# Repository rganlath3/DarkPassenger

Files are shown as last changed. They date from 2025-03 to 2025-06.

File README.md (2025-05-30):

# Dark Passenger



[]()

A modular payload for use as a ROS learning platform. Each floor of the chassis delivers different capabilities. The initial design is mounted on a differential drive roomba with plans to expand to treaded or quad-coptor platforms.

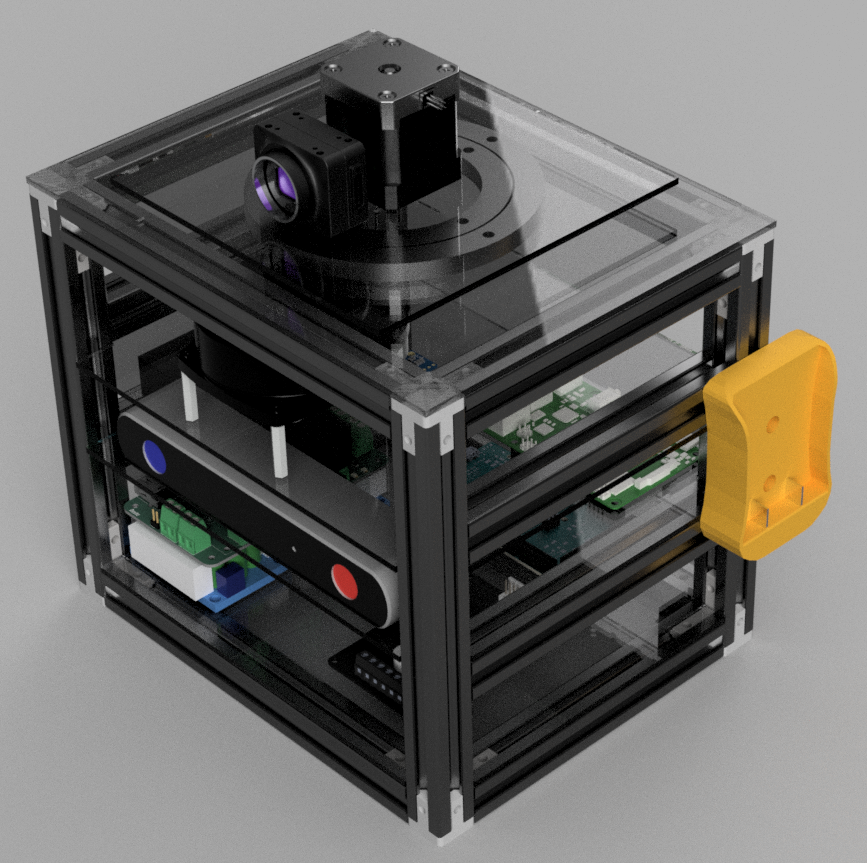
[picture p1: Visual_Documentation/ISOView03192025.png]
Dark Passenger Iso View


<!-- ABOUT THE PROJECT -->
## About The Project
The idea was to reuse a cheap roomba to create a platform for learning ROS2 and sensor integration. The end goal is to have a project incorporate aluminum extrusion chassis, working with acrylic, ESP32-S3, KiCAD PCB Development, stepper motors, thermal camera, depth camera, LIDAR, slip rings, DC motor controllers, encoders, 3D printing, INS sensor fusion, relays, GPS, SLAM, NAV2 (navigation stack) and power distribution.

### Design Tools & Requirements

#### Software Requirements
- VS Code (Programming IDE)
- Autodesk Fusion360 (Free CAD Software)
- KiCAD 9.0 (Open Source PCB Design Software)
- Ultimaker Cura (Free 3D Slicing Software)

#### Hardware Requirements
- Raspberry Pi 5
- 32GB+ SD Card
- 1x Dewalt 20VDC 2Ah Battery

## Hardware Development

### Bill of Materials
Coming Soon

### Hardware Used
#### Chassis
* 2020 T Slot Aluminum Extrusion
* 2020 2-Way Corner Brackets
* 2020 3-Way Corner Brackets
* M5 T Nuts and Screws
* 8x10 Black Translucent Acrylic Sheets 1/8" thick.

#### Floor 1
* 2x DROK Step Down Voltage Regulator
* 2x 3V Relay Modules
* 1x Custom Power Distribution PCB
* 1x Custom ESP3 GPIO PCB
* 1x ESP32-S3-N8R2
* 1x COB LED Strip Yellow
* 1x COB LED Strip Red
* 1x Cytron Dual Channel 10A DC Motor Driver
* 1x Quick Disconnect 12Pin Connector
* 1x MPU9250 IMU
* 1x GY-NEO6MV2 GPS Module

#### Floor 2
* 2x Acer USB Powered Hub
* 1x Raspberry Pi 5 (SBC)
* 1x Respeaker Microphone Array
* 1x ZED Stereo Labs Depth Camera

#### Floor 3
* 1x A1M8 RPLIDAR LIDAR Sensor
* 1x GPS Antenna

#### Floor 4
* 1x Custom ESP3 GPIO PCB
* 1x ESP32-S3-N8R2
* 1x Taidacent Hollow Slip Ring (Maybe 2x)
* 1x 5mm Flange Coupler
* 2x TMC2209 V1.3 Stepper Motor Driver
* 2x NEMA 17 Stepper (2A, 59Ncm), 48mm
* 1x Chameleon Camera Teledyne CM3-U3-13S2C-CS
* 3x 3V Relay Modules
* 1x MDD3A Dual Channel 3A DC Motor Driver
* 1x NERF Gun Gearbox
* 1x Laser Diode, 5V 1mA
* 1x COB LED Strip Yellow
* 1x 5V or 12V Cooling Fan

#### Misc
* Various Capacitors, Resistors, SMD LEDs, JST Connectors, Wire Crimps, etc.
* Various stranded wire lengths and colors: 16AWG, 22AWG.
* 1x 2.1mm DC Barrel Jacks Pair (Power Input)
* 1x SPST 20A Heavy Duty Toggle Switch (Projector Power and Pi Power)
* 2x SPST 5A Mini Toggle Switch (LED Power)
* 3D Printer: Creality CR-10SProV2

### Internal Block Diagram
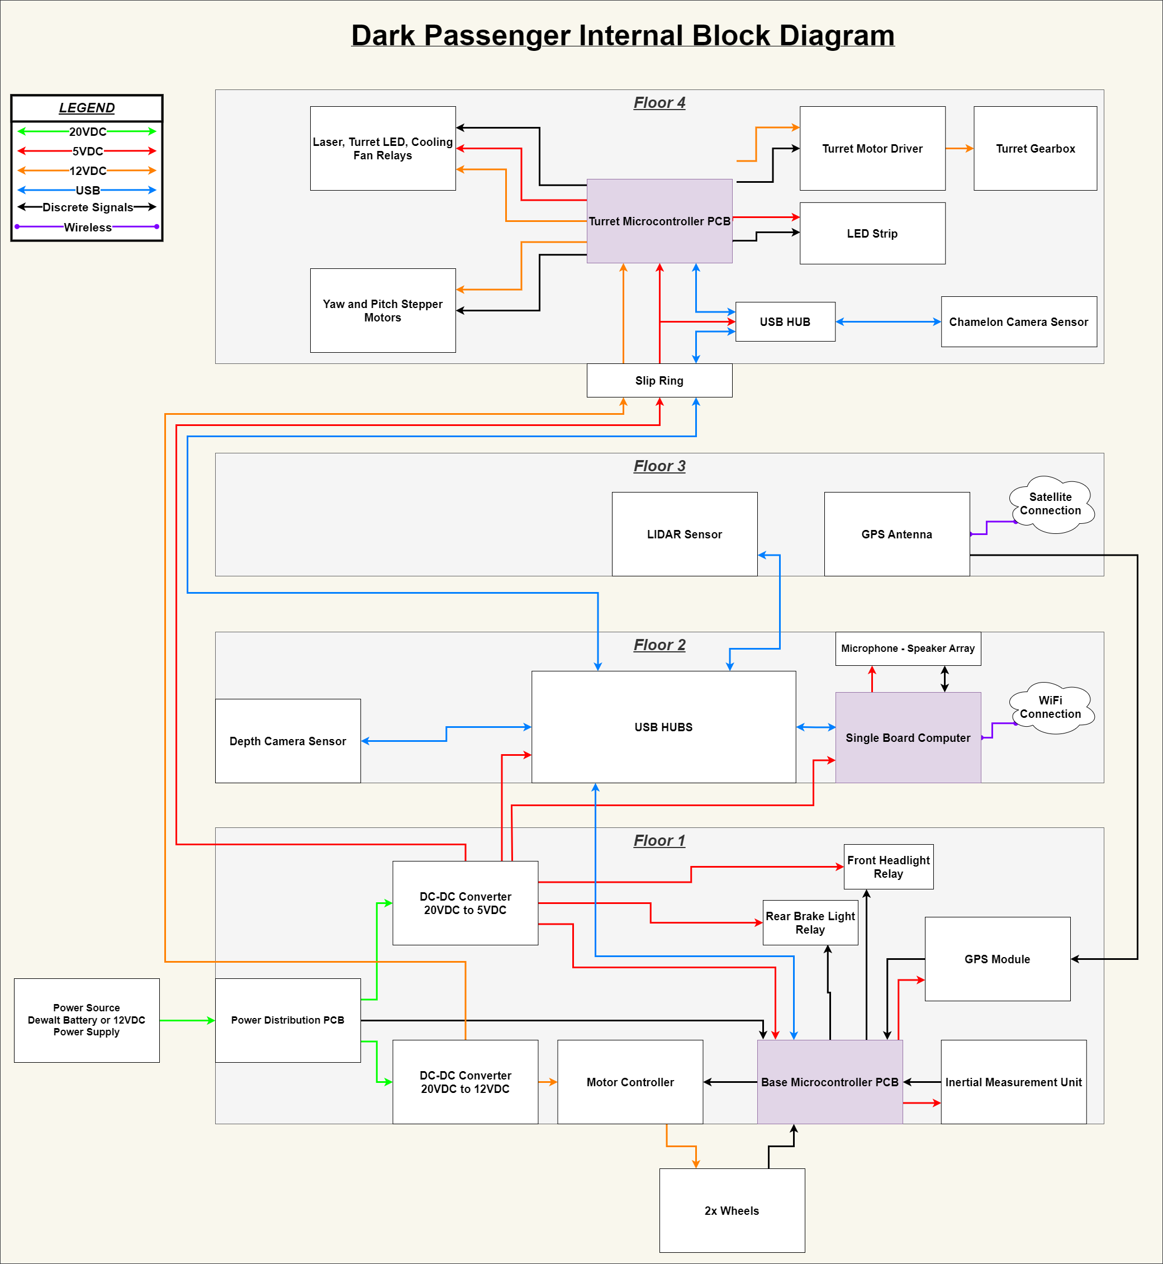
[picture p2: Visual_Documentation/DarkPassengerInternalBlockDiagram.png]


### Electrical Interconnect Diagram
[Electrical Interconnect Diagram](/Hardware_Development/DrawIO/DarkPassengerElectricalInterconnect.pdf)
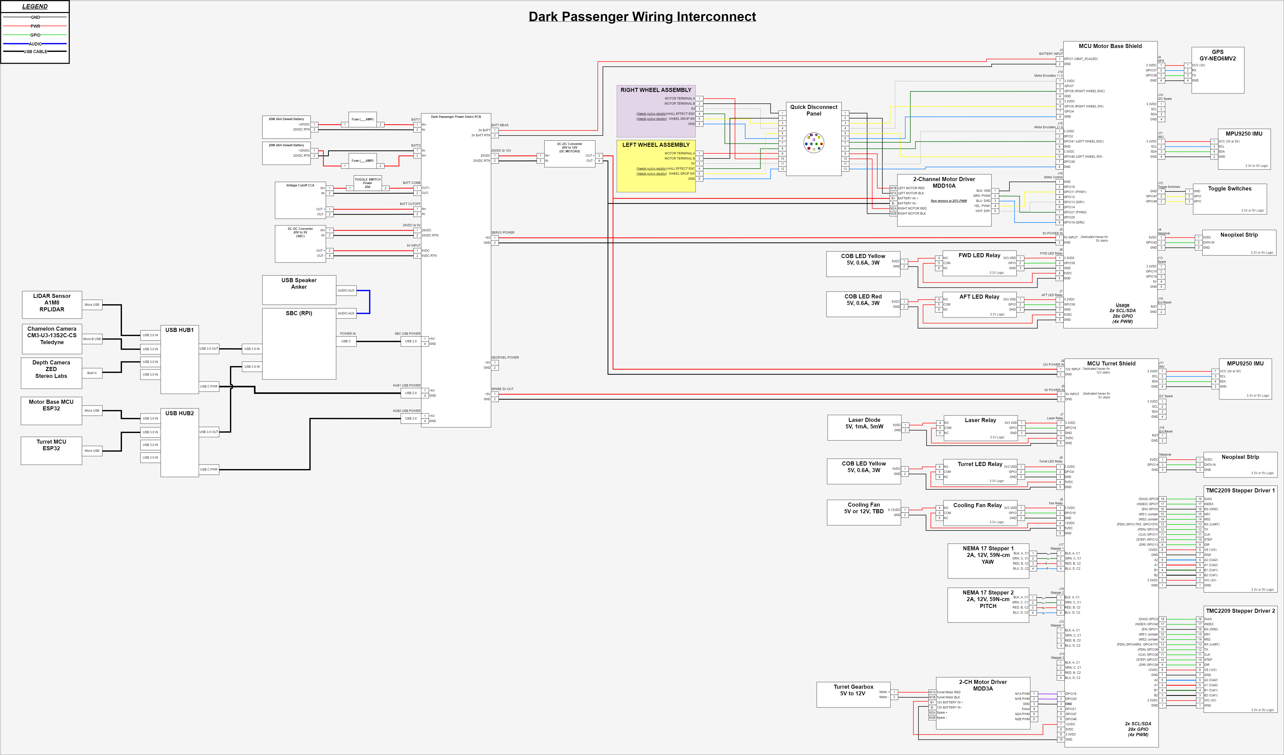
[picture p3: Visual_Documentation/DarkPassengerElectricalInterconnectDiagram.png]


### PCBs
#### Power Distribution PCB
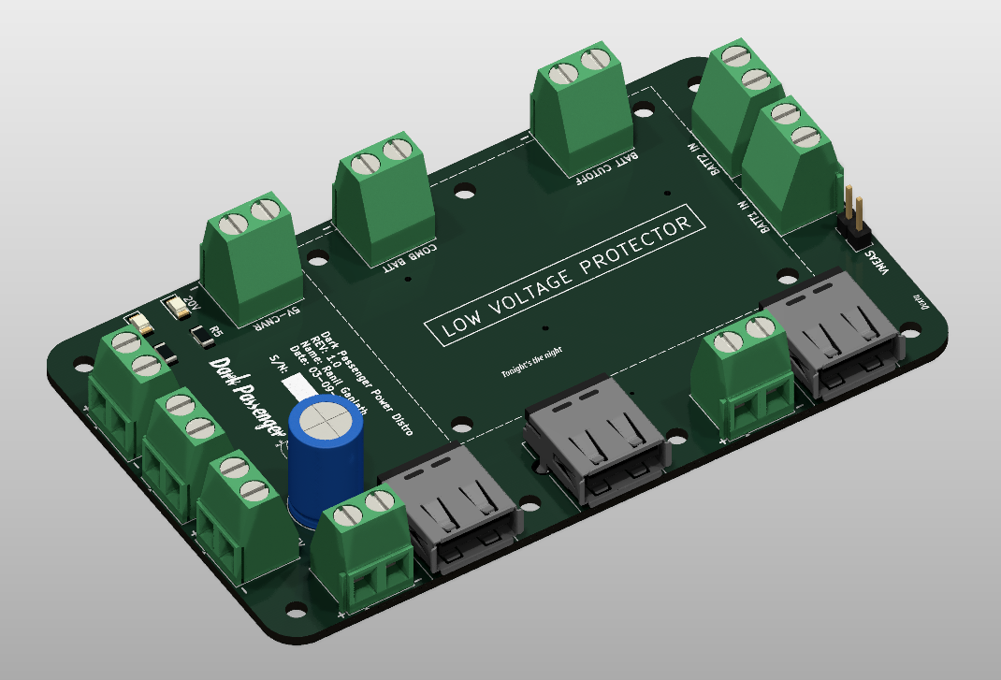
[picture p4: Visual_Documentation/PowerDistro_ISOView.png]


This PCB is used to stack 2x DC-DC converters below and a voltage cutoff board on the top. This PCB distributes power from battery inputs to get converted to 12V and 5V. It interfaces with the following components:

- Up to 2x 2Ah Dewalt Batteries
- Voltage Cutoff CCA (TBD)
- 20VDC to 5VDC Converter (TBD)
- 20VDC to 12VDC Converter (TBD)
- 3x Powered USB Ports
- Spare I2C

#### Base MCU PCB
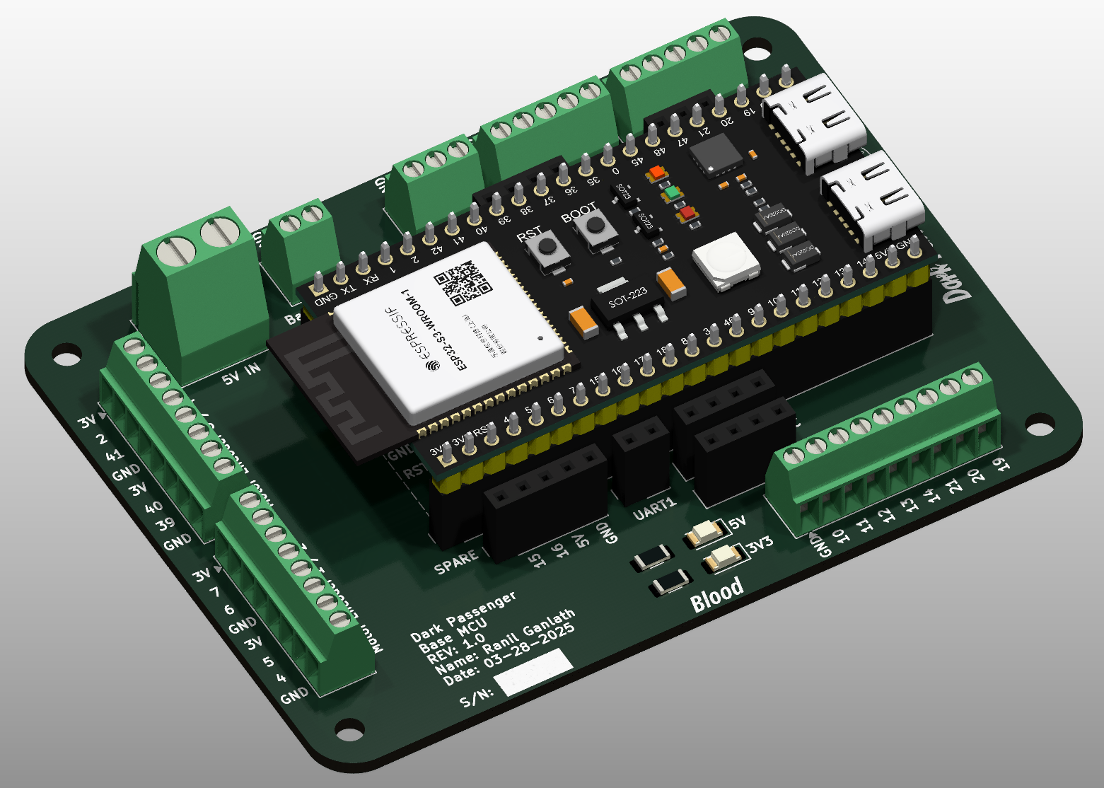
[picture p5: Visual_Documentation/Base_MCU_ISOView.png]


This PCB is used to interface an ESP32-S3 with the following components:

- GPS Module (GY-NEO6mV2)
- MPU9250 IMU
- Spare I2C
- 2x Toggle Switches
- Neopixel Strip
- 2x Spare GPIOs
- External Reset
- 2x Channel Motor Driver (MDD10A)
- Battery Scaled Input
- Motor Encoders
- FWD LED Relay
- AFT LED Relay
- 5V Distribution

#### Turret MCU PCB
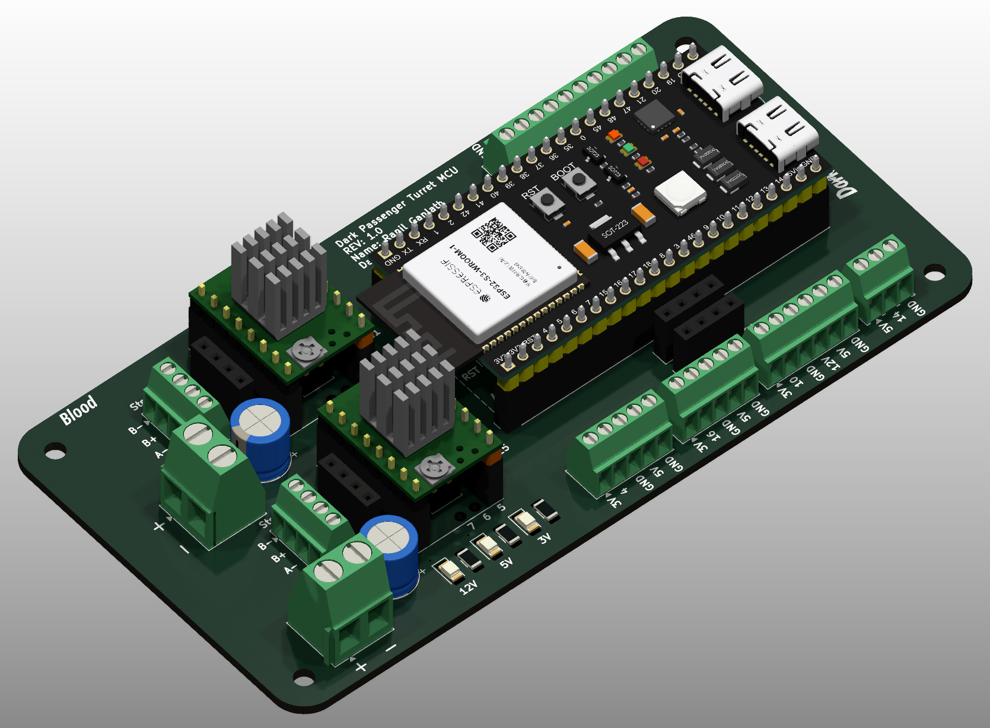
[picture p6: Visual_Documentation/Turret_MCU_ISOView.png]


This PCB is used to interface an ESP32-S3 with the following components:

- GPS Module (GY-NEO6mV2)
- MPU9250 IMU
- Spare I2C
- Neopixel Strip
- External Reset
- 2x Channel Motor Driver (MDD3A)
- 2x NEMA17 Stepper Motors
- 2x TMC2209 Stepper Driver
- Laser Relay
- Turret LED Relay
- Cooling Fan Relay
- 5V Distribution
- 12V Distribution

### Power Budget and Power Draw
TBD

## Software Development
TBD
<!-- GETTING STARTED -->
## Getting Started

TBD
### Prerequisites
TBD

### Installation

TBD

### Common Issues

TBD

## Assets

TBD

<!-- ROADMAP -->
## Roadmap
- [] TBD

<p align="right">(<a href="#readme-top">back to top</a>)</p>

<!-- CONTRIBUTING -->
## Contributing & Donations

Any donation helps to support parts for future open source projects!
[Buy Me a Coffee ☕](https://www.buymeacoffee.com/rganlath)

Contributions are what make the open source community such an amazing place to learn, inspire, and create. Any contributions you make are **greatly appreciated**.

If you have a suggestion that would make this better, please fork the repo and create a pull request. You can also simply open an issue with the tag "enhancement".
Don't forget to give the project a star! Thanks again!

<p align="right">(<a href="#readme-top">back to top</a>)</p>

<!-- LICENSE -->
## License
The contents of this project itself is licensed under CERN-OHL-S-2.0 and the underlying source code is licensed under GNU GPLv3. Both of these licenses require attribution.

<p align="right">(<a href="#readme-top">back to top</a>)</p>

<!-- CONTACT -->
## Contact

Ranil Ganlath - ranil.ganlath@gmail.com

Project Link: TBD

<p align="right">(<a href="#readme-top">back to top</a>)</p>

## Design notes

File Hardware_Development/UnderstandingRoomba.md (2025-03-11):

# LEGAL DISCLAIMER

"LEGAL DISCLAIMER: This documentation is created solely for educational and personal use purposes. As the owner of a second-hand Roomba 891 device, I am documenting connector pinouts, wire color schemes, and sensor specifications to facilitate my personal educational projects and to repurpose components from this specific device that is no longer functional.
This information is compiled due to the limited availability of technical documentation for the Roomba series and is intended to aid in understanding how to interface with and reuse these components in personal educational platforms. I am expressly NOT conducting proprietary circuit analysis or reverse engineering of protected intellectual property.
All information presented is derived from direct observation of physical components and is limited to interface specifications necessary for reuse of discrete parts. No proprietary software, firmware, or protected algorithms are being analyzed or reproduced.
I acknowledge that iRobot retains all applicable intellectual property rights to their products and designs. This documentation does not claim ownership of any iRobot intellectual property and is not affiliated with, endorsed by, or sponsored by iRobot Corporation.
I will promptly remove any content upon notification that it may violate any applicable terms of service, end-user license agreements, or intellectual property rights. This documentation is provided without warranty of any kind and is not intended for commercial purposes."

# Primary Circuit Card Assembly

# Wheels 

# Vaccum Motor

# Bristle Motor

# Side Bumpers

#

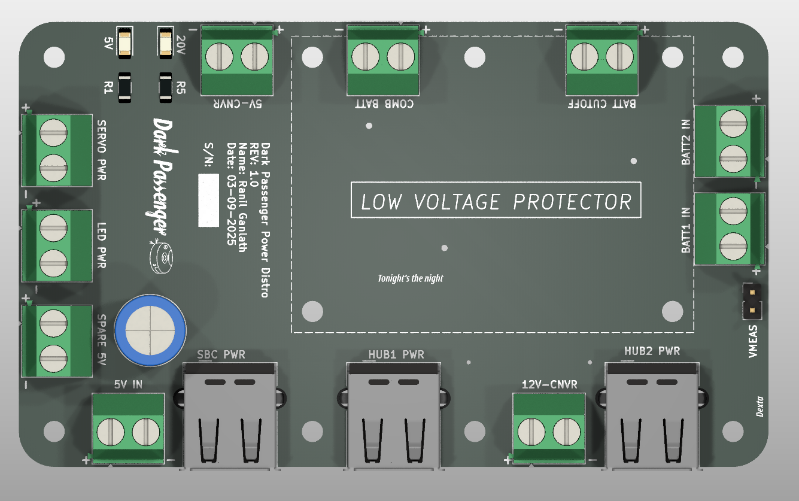
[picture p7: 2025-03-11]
Visual_Documentation/PowerDistro_TopView.png

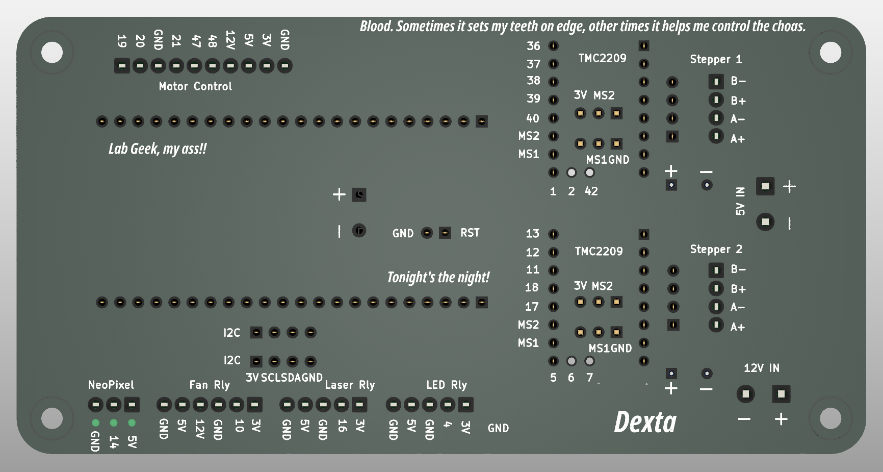
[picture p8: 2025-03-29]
Visual_Documentation/Turret_MCU_BottomView.png

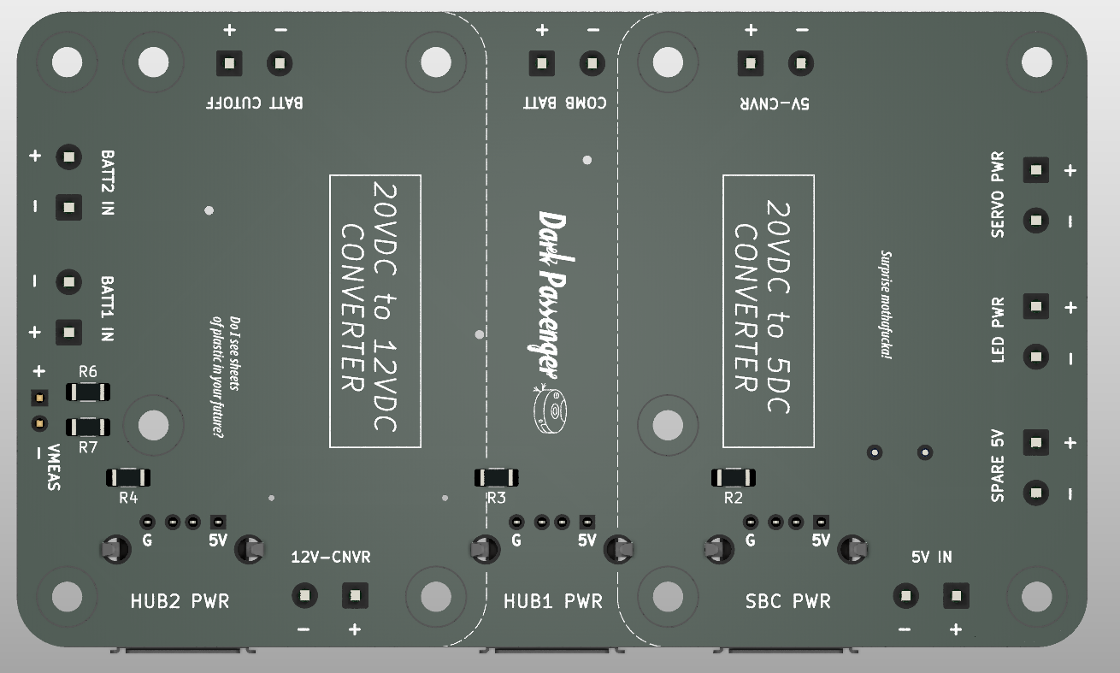
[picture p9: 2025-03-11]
Visual_Documentation/PowerDistro_BottomView.png

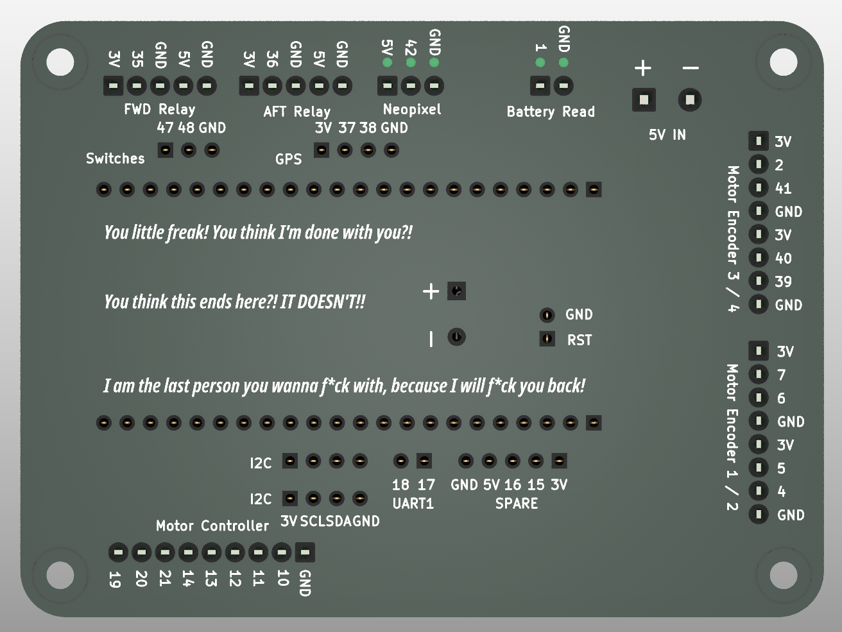
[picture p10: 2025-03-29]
Visual_Documentation/Base_MCU_BottomView.png

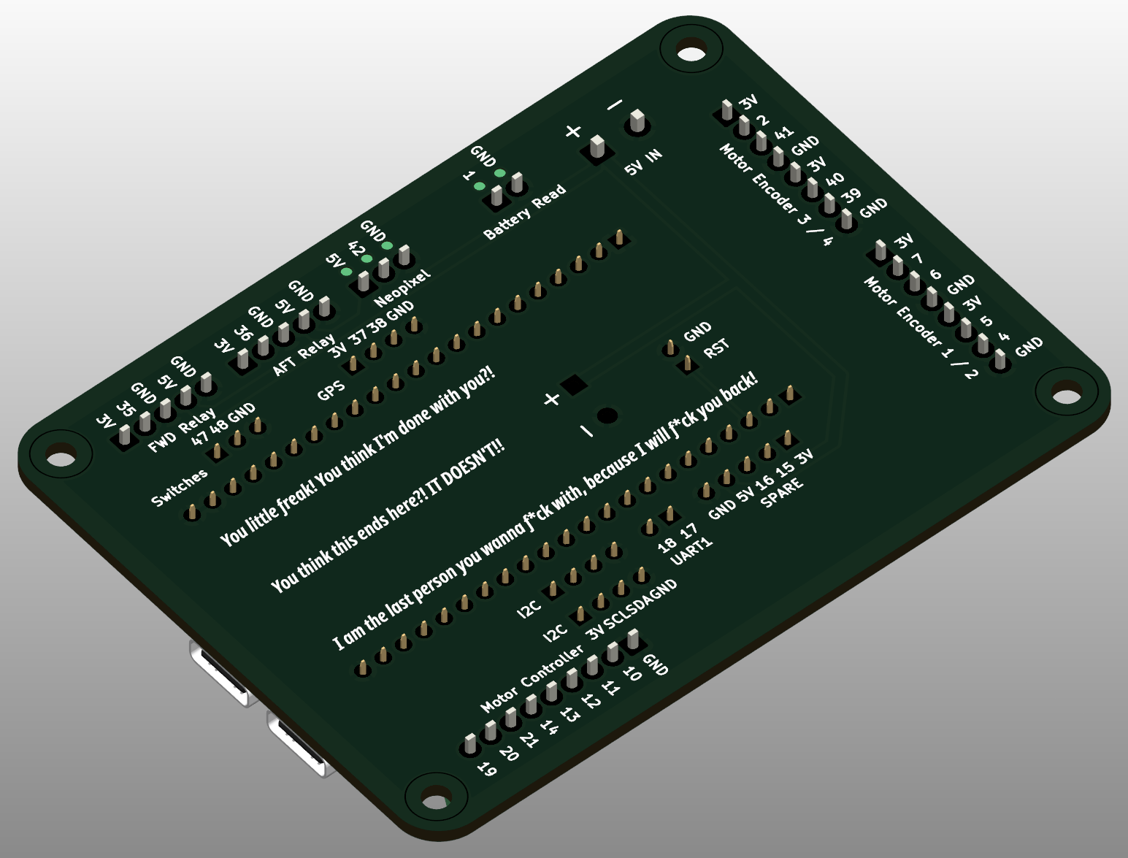
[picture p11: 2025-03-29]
Visual_Documentation/Base_MCU_ISOUndersideView.png

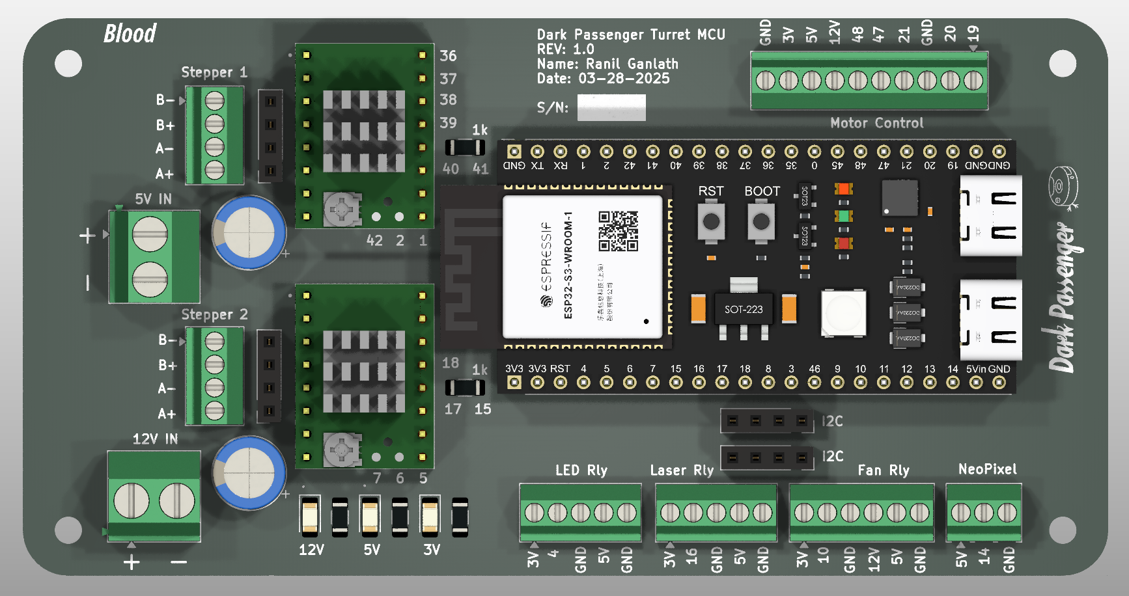
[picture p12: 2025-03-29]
Visual_Documentation/Turret_MCU_TopView.png

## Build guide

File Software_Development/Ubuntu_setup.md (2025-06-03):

# Dark Passenger ROS2 Setup and Configuration



[]()

### Generic Software Tools to Install

### Generic Software Tools to Install with Ubuntu 24.04
sudo apt update
sudo apt upgrade
sudo apt install git terminator chromium-browser gedit python3-pip
sudo snap install --classic code

#### VSCode Extensions
Remote Development by Microsoft
CMake Tools by Microsoft
C/C++ by Microsoft
C/C++ Extension Pack by Microsoft
Python by Microsoft
Python Debugger by Microsoft
Pylance by Microsoft
ROS by Microsoft
URDF by smilerobotics
URDF Visualizer by morningfrog
XML Tools by Josh Johnson

### Cloning this repo
I have a ROS2 workspace built into the repo so all you need to do is clone this repo into a directory of your choice. I am using a folder called "github" in my root directory.
cd ~/github/

git clone https://github.com/rganlath3/DarkPassenger.git

### SSH Setup
sudo apt install openssh-server

### Installing ROS2 Jazzy Jalisco
https://docs.ros.org/en/jazzy/Installation/Ubuntu-Install-Debs.html
Verify ROS2 was installed correctly using cpp talker and py listener.

#### Configure your ROS2 environment
Source your ROS2 install in your shell startup script.
```echo "source /opt/ros/jazzy/setup.bash" >> ~/.bashrc```

Verify the environment is configured properly.
``` printenv | grep -i ROS```

You should get ROS_VERSION=2, ROS_PYTHON_VERSION=3, and ROS_DISTRO=jazzy

Navigate to the workspace and run this command to find the packages
```source install/setup.bash```

Add the path of the ROS2 workspace to the startup script as well. (gedit ~/.bashrc)
```source /opt/ros/jazzy/setup.bash```
```source ~/github/DarkPassenger/ROS2/dp_ws/install/setup.bash```
```cd ~/github/DarkPassenger/ROS2/dp_ws```

#### Install ROS2 Tools and Gazebo Harmonic Simulator
```sudo apt-get install ros-${ROS_DISTRO}-ros-gz```
```sudo apt install ros-jazzy-twist-mux```
```sudo apt install ros-jazzy-twist-stamper```
```sudo apt install ros-jazzy-joy*```
```sudo apt install ros-jazzy-joint-state-publisher```

#### Installing ROS2 Control
```sudo apt install ros-jazzy-ros2-control```
```sudo apt install ros-jazzy-ros2-controllers```
```sudo apt install ros-jazzy-gz-ros2-control```

Test your gazebo install
```ros2 launch ros_gz_sim gz_sim.launch.py gz_args:=empty.sdf```

In Gazebo Classic, topics were easily shared between Gazebo and ROS2 interface. Now they are separate and we need to use a bridge to link the two topic names together. Often times, the easiest solution to a problem is that a topic is only in one environment and isn't bridged. We can check this by using the topic viewer in Gazebo and comparing it to the ROS2 topic list command output. We define the data we are bridging using the gz_bridge.yaml file and specify it in our launch command. Image topics use their own launch command.

Gazebo Harmonic differs from the "Classic" Gazebo meaning that there's a few changes to make to packages that are used to interfacing with classic gazebo.
1. Modify package.xml and CMakeLists.txt files replace "gazebo, "gazebo_ros_pkgs", etc with packages from "ros_gz"
2. Edit launch files that start Gazebo
3. Update the world SDFormat File
4. Edit launch files that spawn models.
5. Edit modelSDFormat files.
6. Bridge ROS topics.

### Arduino Setup
Install Arduino 1.8.19 IDE

Add permissions to use serial ports.
```sudo usermod -a -G dialout $USER```

Note: You will need to reboot your computer for the changes to take effect. Install the Arduino IDE on your computer. This tutorial used 1.8.19. Verify the code works using the Arduino IDE serial monitor. If it works, record the device's serial port using the following command:

```ls /dev/tty*```
Note: The serial port will be /dev/ttyUSB* or /dev/ttyACM*. 

Verify installation
```python3```
```import serial```
```import time```
```esp32=serial.Serial(port='/dev/ttyACM0', baudrate=115200, timeout=.1)```
```print(esp32.readline())```

Now we can write a Python node that communicates with your ESP32 board through the serial port.

#### Interfacing with ESP32 over Serial
I created a custom python ROS2 package for interfacing with both the base and turret (future implementation) microcontrollers.
The base_bridge.py connects the ESP32 with 2x topics: serial_tx and serial_rx. Other nodes interface with these topics to generate commands or use the input datastream.
The base_rx_topic_router processes the serial_rx topic and formats and packages data out to relevant topics.

### RPLidar Setup
Install the RPLIDAR ROS Package
```sudo apt install ros-jazzy-rplidar-ros```

Add USB Reading Permissions:
```sudo usermod -a -G dialout $USER```

Check List of USB Devices
```ls -1 /dev |grep ttyUSB```

Run the Lidar Node:
```ros2 run rplidar_ros rplidar_composition --ros-args -p serial_port:=/dev/ttyUSB0 -p frame_id:=laser_frame -p angle_compensate:=true -p scan_mode:=Standard```

To Stop The motor:
```ros2 service call /stop_motor std_srvs/srv/Empty {}```

To Start the motor:
```ros2 service call /start_motor std_srvs/srv/Empty {}```

Here is a good launch file test script:
```ros2 launch rplidar_ros view_rplidar.launch.py```

If a closed script is still hogging the USB port, you can run this command:
```killall rplidar_composition```

### Camera (Software)
The camera is outputting it's uncompressed image out to the topic: /camera/image_raw

In order to compress the images (eats up processing power but greatly reduces bandwidth for video stream), we need to install a ROS transport plugin.
```sudo apt install ros-jazzy-image-transport-plugins```
```sudo apt install ros-jazzy-rqt-image-view```

To visually see ros image topics, use ```ros2 run rqt_image_view  rqt_image_view```

To convert between compressed and uncompressed feeds, we can use:
ros2 run image_transport list_transports

Ex. Compressed to Raw
ros2 run image_transport republish compressed raw --ros-args -r in/compressed:=/camera/image_raw/compressed -r out:=/camera/image_raw/raw/uncompressed
Note: This doesn't seem to be working as the output is not being configured correctly. I couldnt find any similar errors online.

### ZED Depth Camera
I am using an RGBD camera in Gazebo (URDF plugin) and passing the image and depth_image info using gz_bridge. For the depth point data, I am....

The ZED camera requires CUDA meaning it needs an NVIDIA graphics card to run. The development machine or a JETSON must be used. 
https://github.com/stereolabs/zed-ros2-wrapper

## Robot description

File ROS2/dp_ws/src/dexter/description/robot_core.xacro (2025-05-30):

<?xml version="1.0"?>
<robot xmlns:xacro="http://www.ros.org/wiki/xacro">

<!-- Made by Ranil Ganlath: ranil.ganlath@gmail.com -->
<!-- This is the main urdf script for the Dark Passenger Payload mounted on a roomba chassis -->

  <!-- This makes inertia estimates easier -->
    <xacro:include filename="inertial_macros.xacro"/>

  <!-- Material Colors -->
    <material name="orange">
        <color rgba="${255/255} ${108/255} ${10/255} 1.0"/>
    </material>

    <material name="brown">
        <color rgba="${222/255} ${207/255} ${195/255} 1.0"/>
    </material>

    <material name="yellow">
        <color rgba="1 1 0.2 1" />
    </material>

    <material name="black">
        <color rgba="0.2 0.2 0.2 1" />
    </material>

    <material name="gray">
        <color rgba="0.4 0.4 0.4 1" />
    </material>

    <material name="white">
        <color rgba="0.7 0.7 0.7 1" />
    </material>

    <material name="blue">
        <color rgba="0.2 0.2 1 1" />
    </material>

    <material name="red">
        <color rgba="1 0.2 0.2 1" />
    </material>

    <material name="green">
        <color rgba="0.2 1 0.2 1" />
    </material>

    <material name="teal">
        <color rgba="0.2 0.8 1 1" />
    </material>

    <material name="magenta">
        <color rgba="0.8 0.2 0.8 1" />
    </material>

  <!-- XACRO Constants -->
    <xacro:property name="roomba_wheel_radius" value="0.035" />
    <xacro:property name="roomba_wheel_separation" value="0.218" />
    <xacro:property name="roomba_wheel_height_offset" value="0.01" />
    <xacro:property name="roomba_wheel_thickness" value="0.015" />
    <xacro:property name="roomba_wheel_weight" value="0.1" />
    <xacro:property name="caster_wheel_radius" value="0.024" />
    <xacro:property name="caster_wheel_weight" value="0.026" />
    <xacro:property name="caster_wheel_center_offset" value="0.14" />
    <xacro:property name="roomba_chassis_radius" value="0.17145" />
    <xacro:property name="roomba_chassis_height" value="0.075" />
    <xacro:property name="roomba_chassis_weight" value="1.81437" />

    <xacro:property name="payload_chassis_length" value="0.19" />
    <xacro:property name="payload_chassis_width" value="0.24" />
    <xacro:property name="payload_chassis_height" value="0.21" />
    <xacro:property name="payload_chassis_weight" value="3.4473" />


  <!-- Base Link (WORLD)-->
  <link name="base_link"></link>


 <!-- Roomba Chassis Link -->
    <joint name="roomba_chassis_joint" type="fixed">
        <parent link="base_link"/>
        <child link="roomba_chassis"/>
        <origin xyz="0 0 -${roomba_wheel_height_offset}" rpy="0 0 0"/>
    </joint>
    <link name="roomba_chassis">
        <visual>
            <origin xyz ="0 0 ${roomba_chassis_height/2}"/>
            <geometry>
                <cylinder radius="${roomba_chassis_radius}" length="${roomba_chassis_height}"/>
            </geometry>
            <material name="gray"/>
        </visual>
        <collision>
            <origin xyz ="0 0 ${roomba_chassis_height/2}"/>
            <geometry>
                <cylinder radius="${roomba_chassis_radius}" length="${roomba_chassis_height}"/>
            </geometry>
        </collision>
        <xacro:inertial_cylinder mass="${roomba_chassis_weight}" radius="${roomba_chassis_radius}" length="${roomba_chassis_height}">
            <origin xyz="0 0 ${roomba_chassis_height/2}" rpy= "0 0 0"/>
        </xacro:inertial_cylinder>
    </link>

    <gazebo reference="roomba_chassis">
        <material>Gazebo/White</material>
    </gazebo>

<!-- LEFT WHEEL Link -->
    <joint name="left_wheel_joint" type="continuous">
        <parent link="roomba_chassis"/>
        <child link="left_wheel"/>
        <origin xyz="0 ${roomba_wheel_separation/2} ${roomba_wheel_radius - roomba_wheel_height_offset}" rpy="-${pi/2} 0 0"/>
        <axis xyz="0 0 1"/>
    </joint>
    <link name="left_wheel">
        <visual>
            <geometry>
                <cylinder radius="${roomba_wheel_radius}" length="${roomba_wheel_thickness}"/>
            </geometry>
            <material name="yellow"/>
        </visual>
        <collision>
            <geometry>
                <sphere radius="${roomba_wheel_radius}"/>
            </geometry>
        </collision>
        <xacro:inertial_cylinder mass="${roomba_wheel_weight}" radius="${roomba_wheel_radius}" length="${roomba_wheel_thickness}">
            <origin xyz="0 0 0" rpy= "0 0 0"/>
        </xacro:inertial_cylinder>
    </link>
    <gazebo reference="left_wheel">
        <material>Gazebo/Blue</material>
    </gazebo>

<!-- RIGHT WHEEL Link -->
    <joint name="right_wheel_joint" type="continuous">
        <parent link="roomba_chassis"/>
        <child link="right_wheel"/>
        <origin xyz="0 -${roomba_wheel_separation/2} ${roomba_wheel_radius - roomba_wheel_height_offset}" rpy="${pi/2} 0 0"/>
        <axis xyz="0 0 -1"/>
    </joint>
    <link name="right_wheel">
        <visual>
            <geometry>
                <cylinder radius="${roomba_wheel_radius}" length="${roomba_wheel_thickness}"/>
            </geometry>
            <material name="magenta"/>
        </visual>
        <collision>
            <geometry>
                <sphere radius="${roomba_wheel_radius}"/>
            </geometry>
        </collision>
        <xacro:inertial_cylinder mass="${roomba_wheel_weight}" radius="${roomba_wheel_radius}" length="${roomba_wheel_thickness}">
            <origin xyz="0 0 0" rpy= "0 0 0"/>
        </xacro:inertial_cylinder>
    </link>
    <gazebo reference="right_wheel">
        <material>Gazebo/Red</material>
    </gazebo>

<!-- CASTER WHEEL Link -->
    <joint name="caster_wheel_joint" type="fixed">
        <parent link="roomba_chassis"/>
        <child link="caster_wheel"/>
        <origin xyz="${caster_wheel_center_offset} 0 ${caster_wheel_radius - roomba_wheel_height_offset}"/>
    </joint>
    <link name="caster_wheel">
        <visual>
            <geometry>
                <sphere radius="${caster_wheel_radius}"/>
            </geometry>
            <material name="red"/>
        </visual>
        <collision>
            <geometry>
                <sphere radius="${caster_wheel_radius}"/>
            </geometry>
        </collision>
        <xacro:inertial_sphere mass="${caster_wheel_weight}" radius="${caster_wheel_radius}">
            <origin xyz="0 0 0" rpy= "0 0 0"/>
        </xacro:inertial_sphere>
    </link>
    <gazebo reference="caster_wheel">
        <material>Gazebo/Blue</material>
        <mu1 value="0.001"/>
        <mu2 value="0.001"/>
    </gazebo>

 <!-- Payload Chassis Link -->
    <joint name="payload_chassis_joint" type="fixed">
        <parent link="roomba_chassis"/>
        <child link="payload_chassis"/>
        <origin xyz="-${payload_chassis_length/2} 0 ${roomba_chassis_height}" rpy="0 0 0"/>
    </joint>
    <link name="payload_chassis">
        <visual>
            <origin xyz ="${payload_chassis_length/2} 0 ${payload_chassis_height/2}"/>
            <geometry>
                <box size="${payload_chassis_length} ${payload_chassis_width} ${payload_chassis_height}"/>
            </geometry>
            <material name="black"/>
        </visual>
        <collision>
            <origin xyz ="${payload_chassis_length/2} 0 ${payload_chassis_height/2}"/>
            <geometry>
                <box size="${payload_chassis_length} ${payload_chassis_width} ${payload_chassis_height}"/>
            </geometry>
        </collision>
        <xacro:inertial_box mass ="${payload_chassis_weight}" x="${payload_chassis_length}" y="${payload_chassis_width}" z="${payload_chassis_height}">
            <origin xyz ="${payload_chassis_length/2} 0 ${payload_chassis_height/2}" rpy = "0 0 0"/>
        </xacro:inertial_box>
    </link>
    <gazebo reference="payload_chassis">
        <material>Gazebo/Green</material>
    </gazebo>

</robot>

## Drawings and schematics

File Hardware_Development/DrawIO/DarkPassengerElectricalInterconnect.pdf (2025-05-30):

# Quick Disconnect Panel

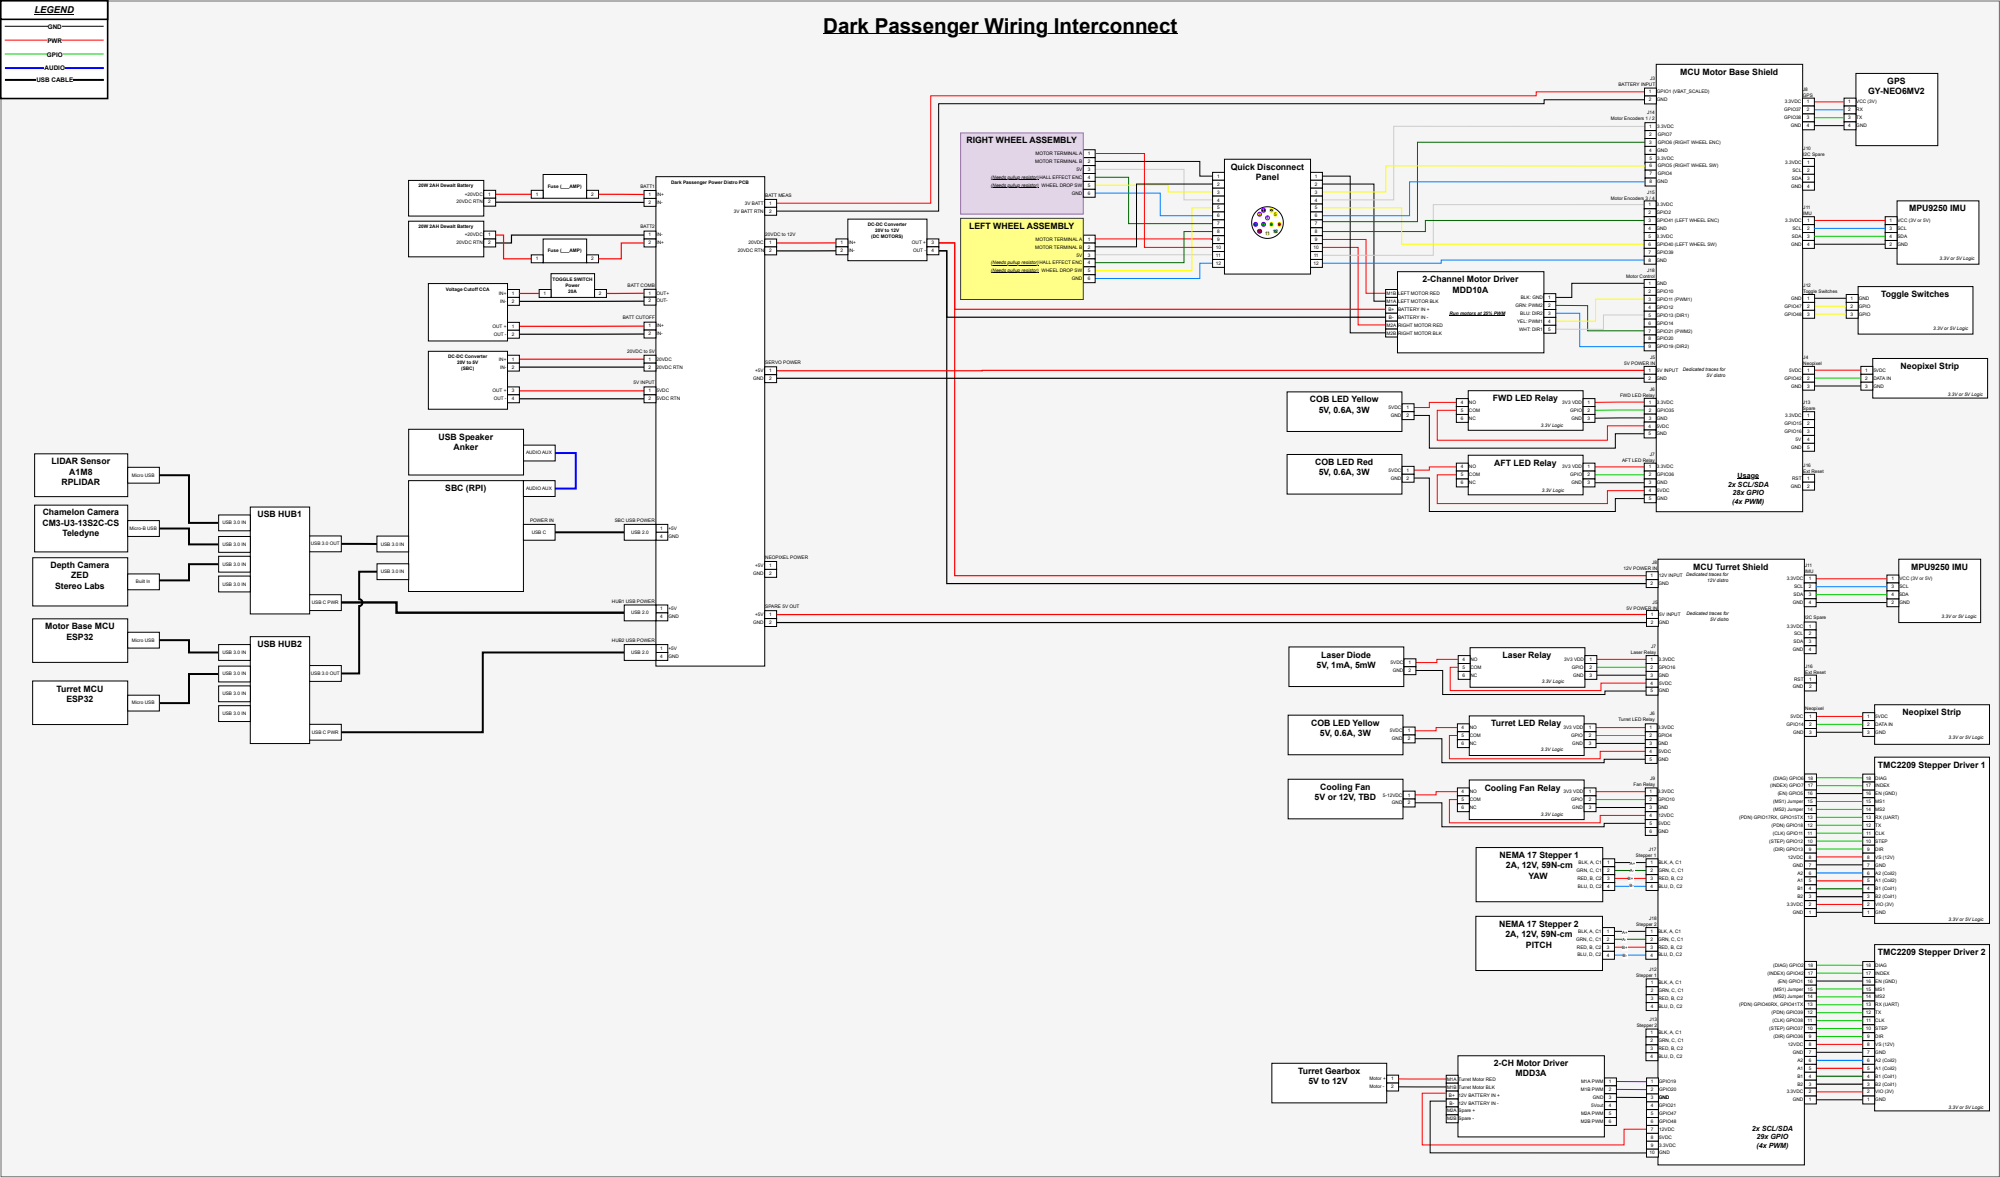
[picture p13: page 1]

Dark Passenger Wiring Interconnect

MCU Motor Base Shield

Dark Passenger Power Distro PCB

Run motors at 25% PWM

Fan Relay Cooling Fan Relay NO
COM

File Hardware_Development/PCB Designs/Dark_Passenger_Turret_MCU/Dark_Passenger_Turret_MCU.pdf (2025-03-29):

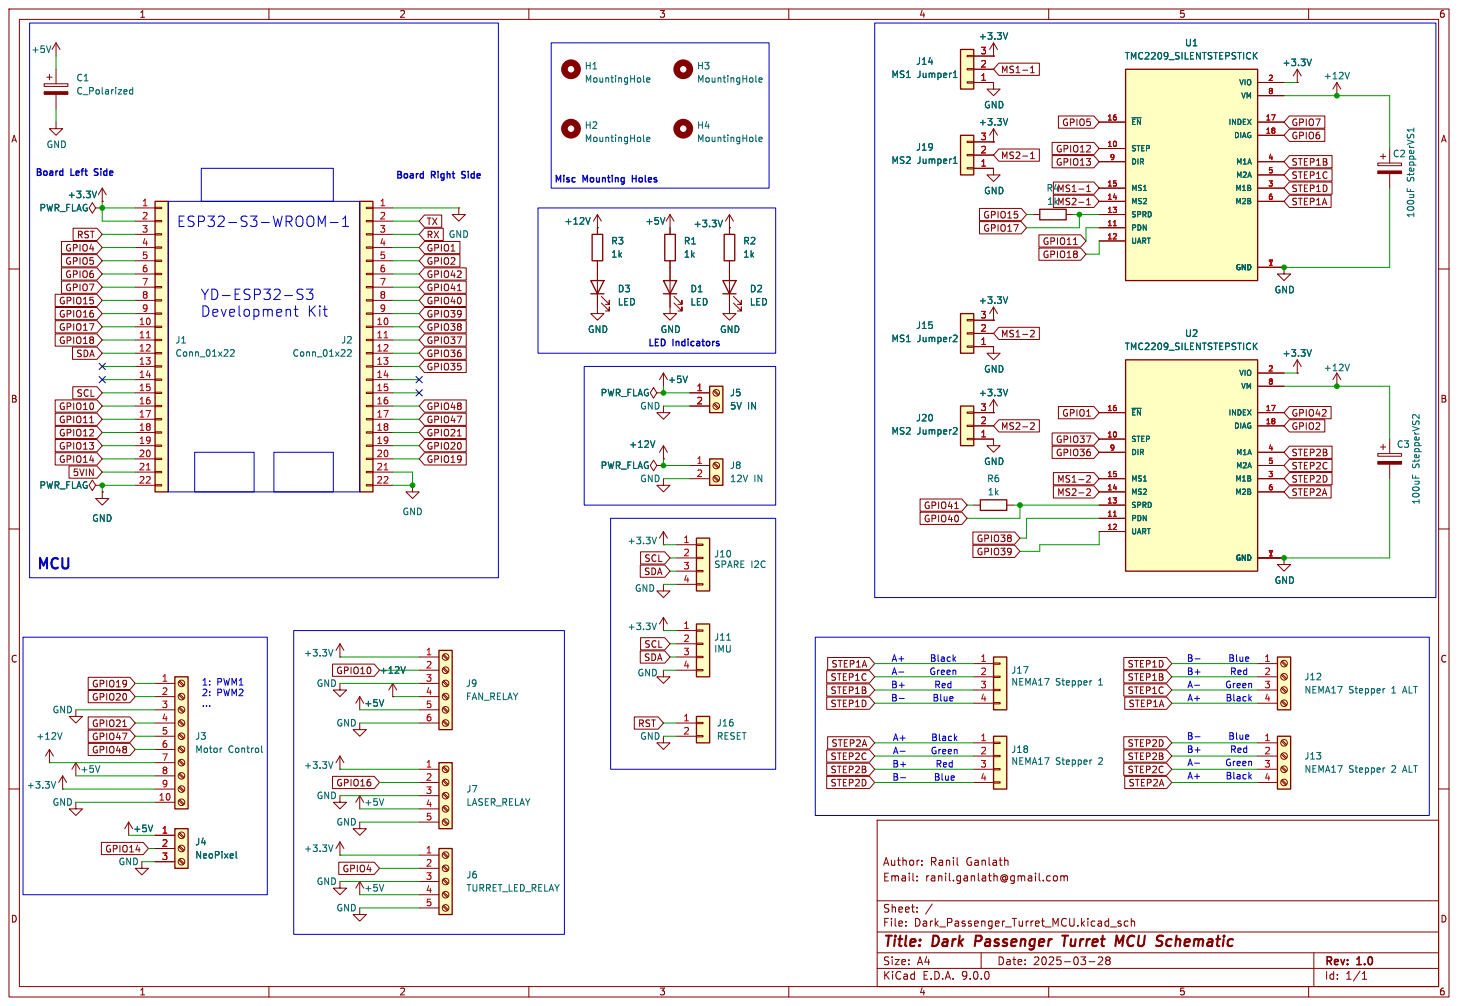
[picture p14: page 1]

LED
IMU GND GND GND GND

File: Dark_Passenger_Turret_MCU.kicad_sch Sheet: / Email: ranil.ganlath@gmail.com

Id: 1/1 Title: Dark Passenger Turret MCU Schematic

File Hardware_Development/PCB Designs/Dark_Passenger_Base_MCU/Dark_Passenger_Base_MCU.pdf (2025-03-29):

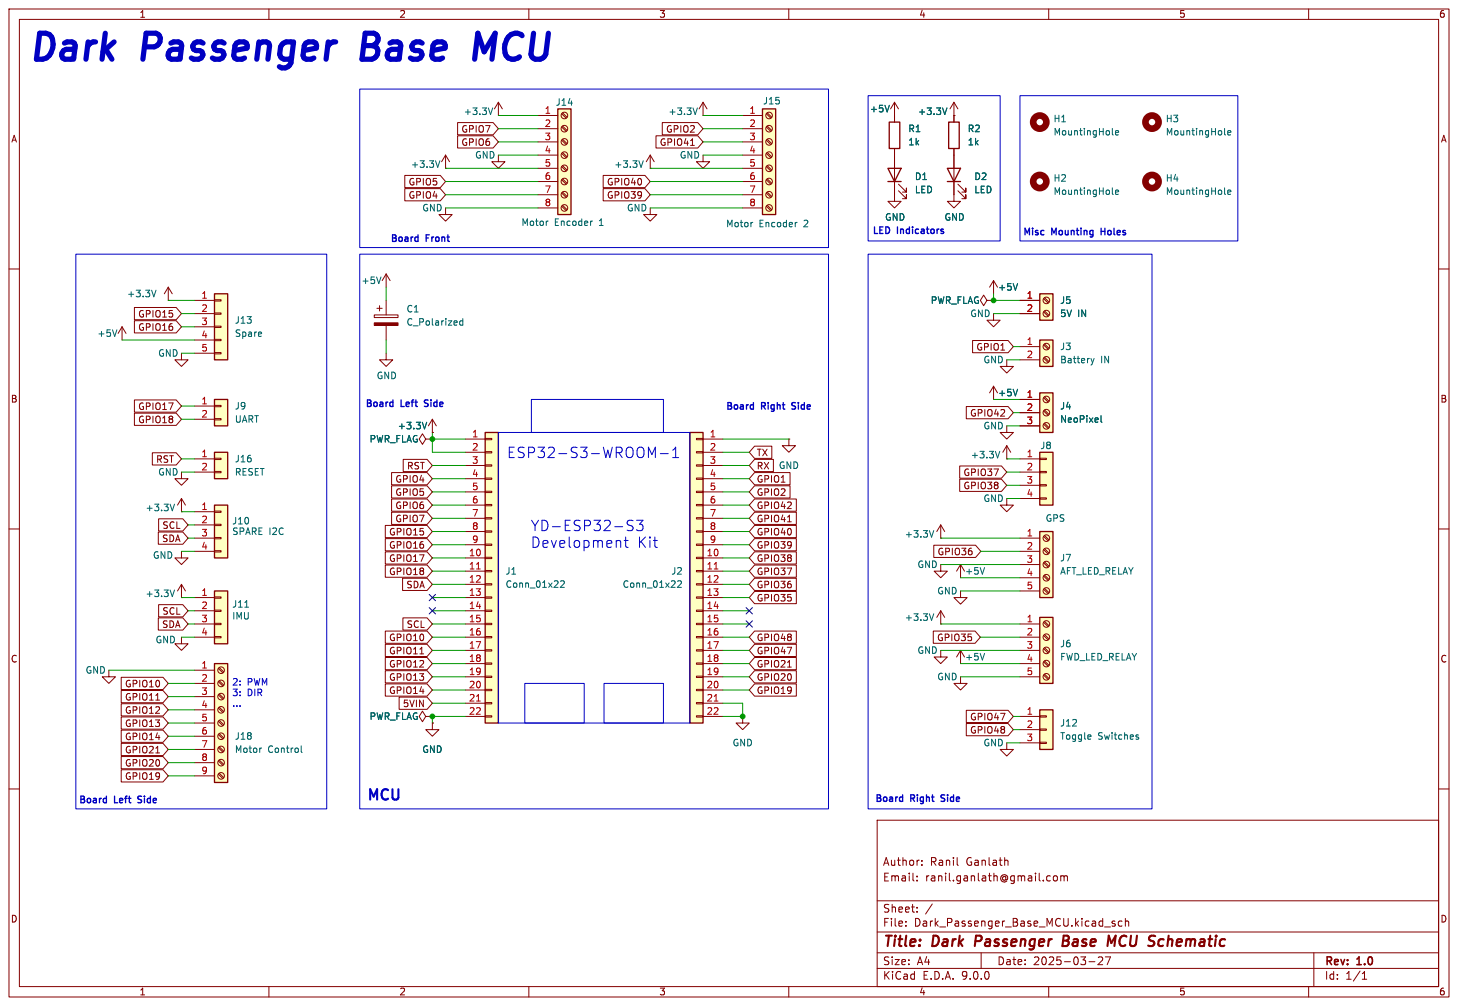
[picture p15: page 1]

Dark Passenger Base MCU

File: Dark_Passenger_Base_MCU.kicad_sch Sheet: / Email: ranil.ganlath@gmail.com

Id: 1/1 Title: Dark Passenger Base MCU Schematic

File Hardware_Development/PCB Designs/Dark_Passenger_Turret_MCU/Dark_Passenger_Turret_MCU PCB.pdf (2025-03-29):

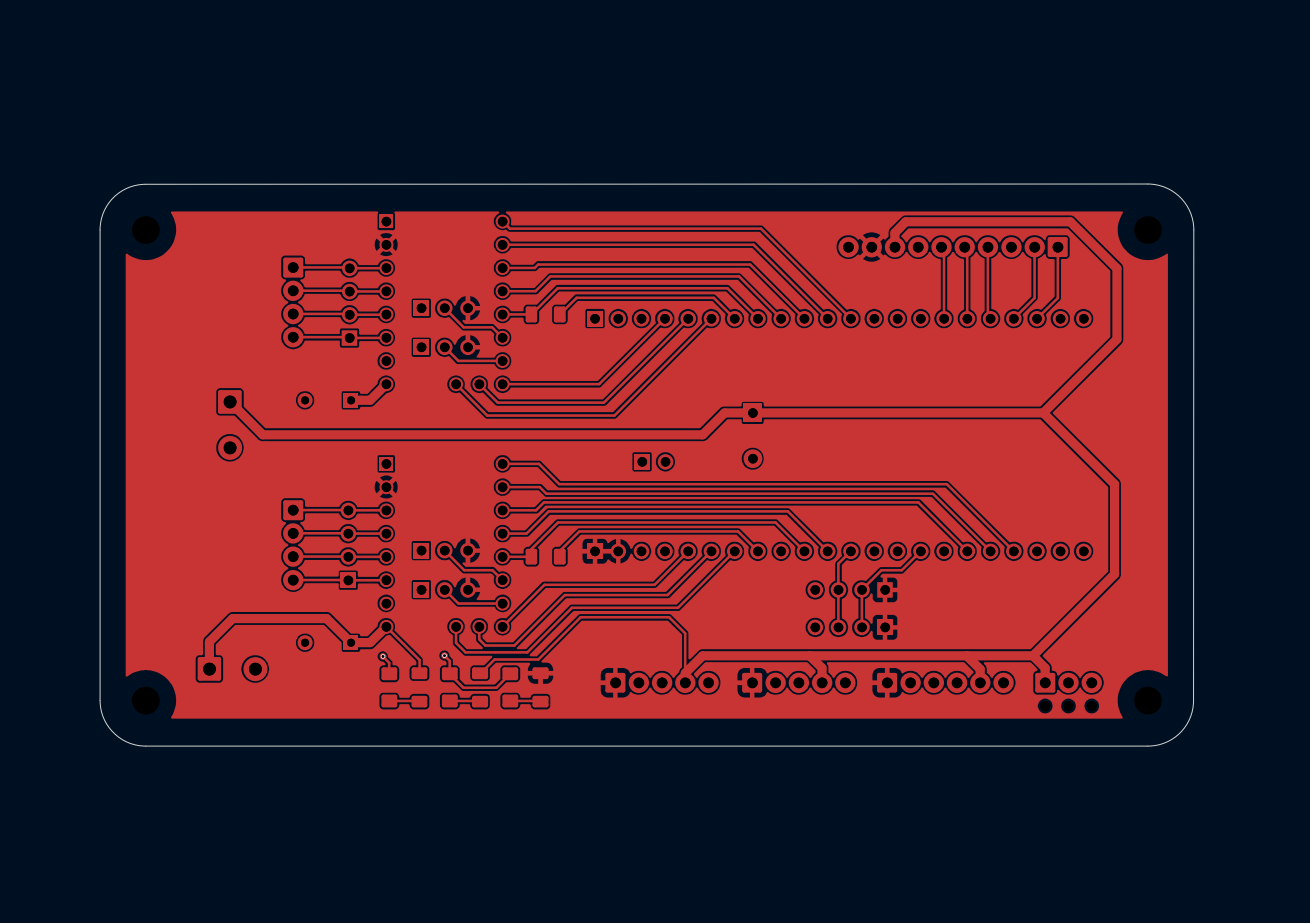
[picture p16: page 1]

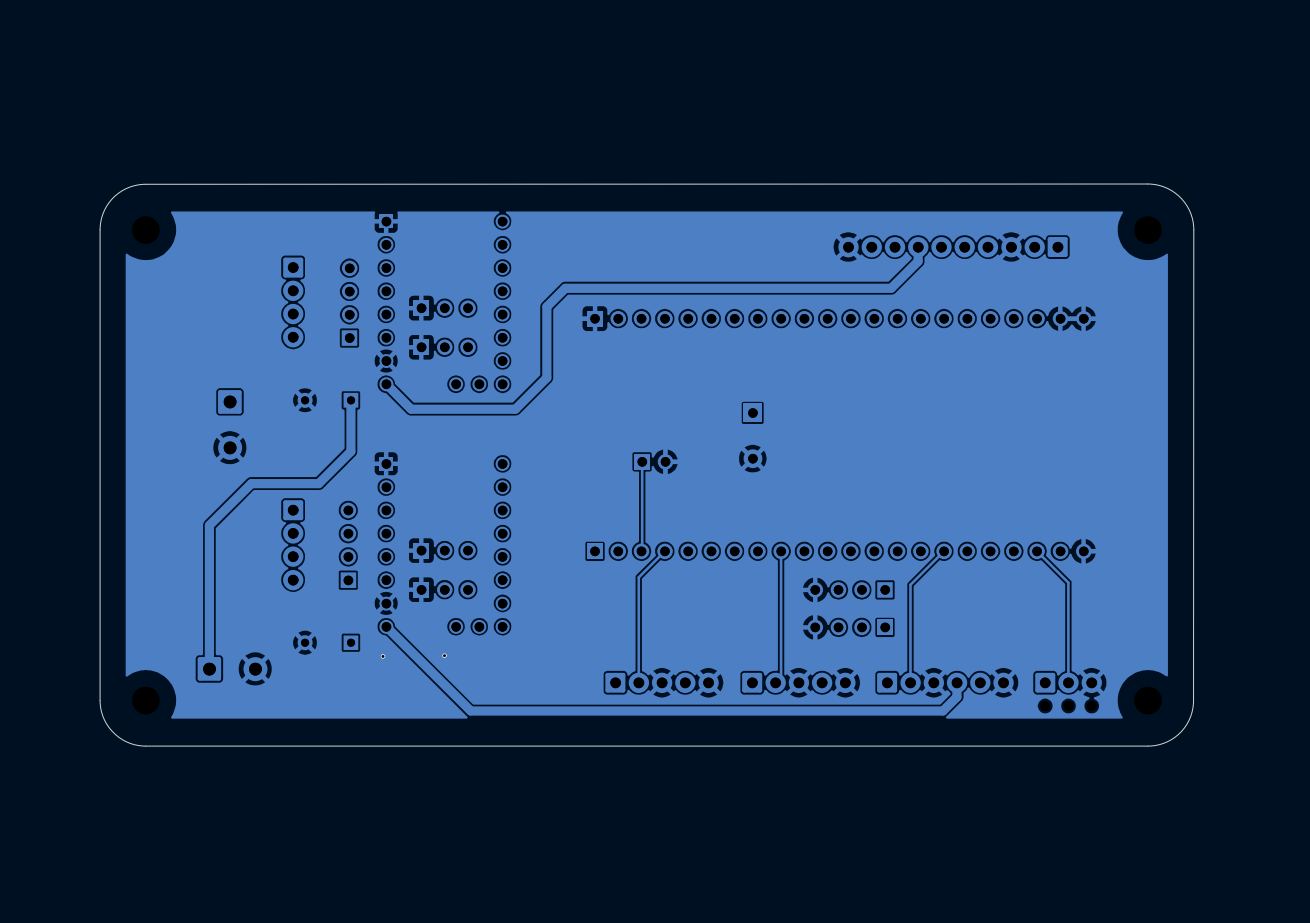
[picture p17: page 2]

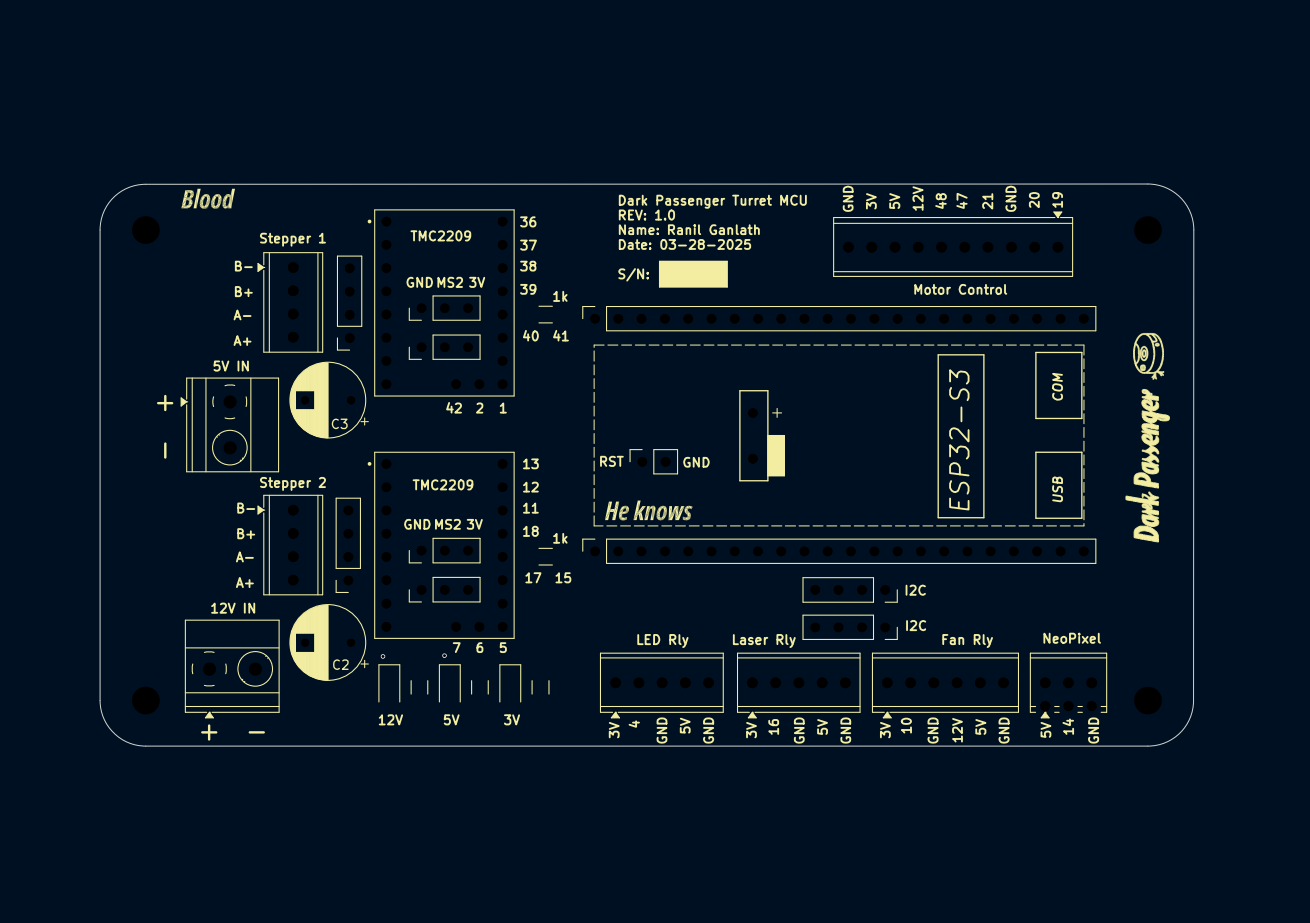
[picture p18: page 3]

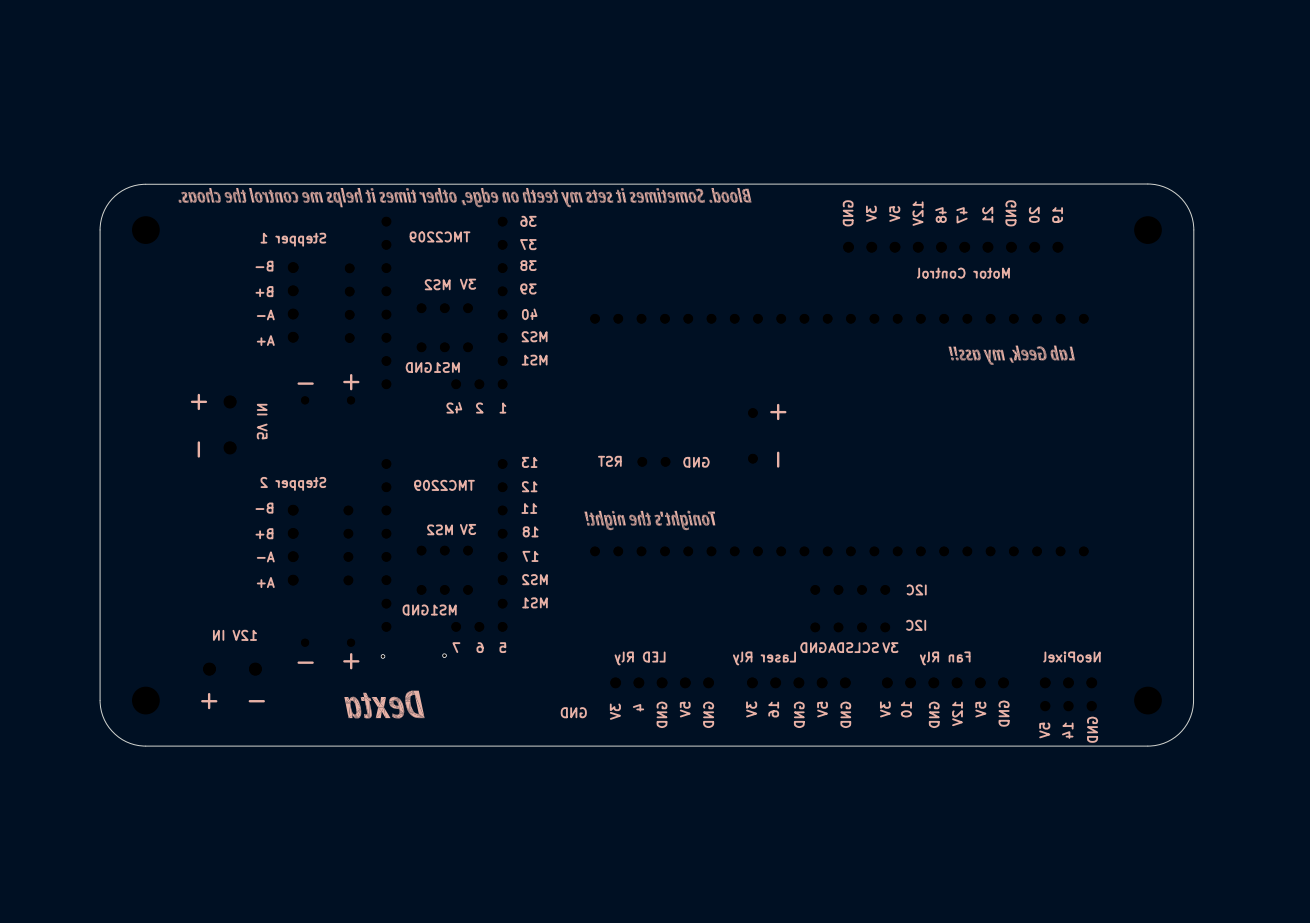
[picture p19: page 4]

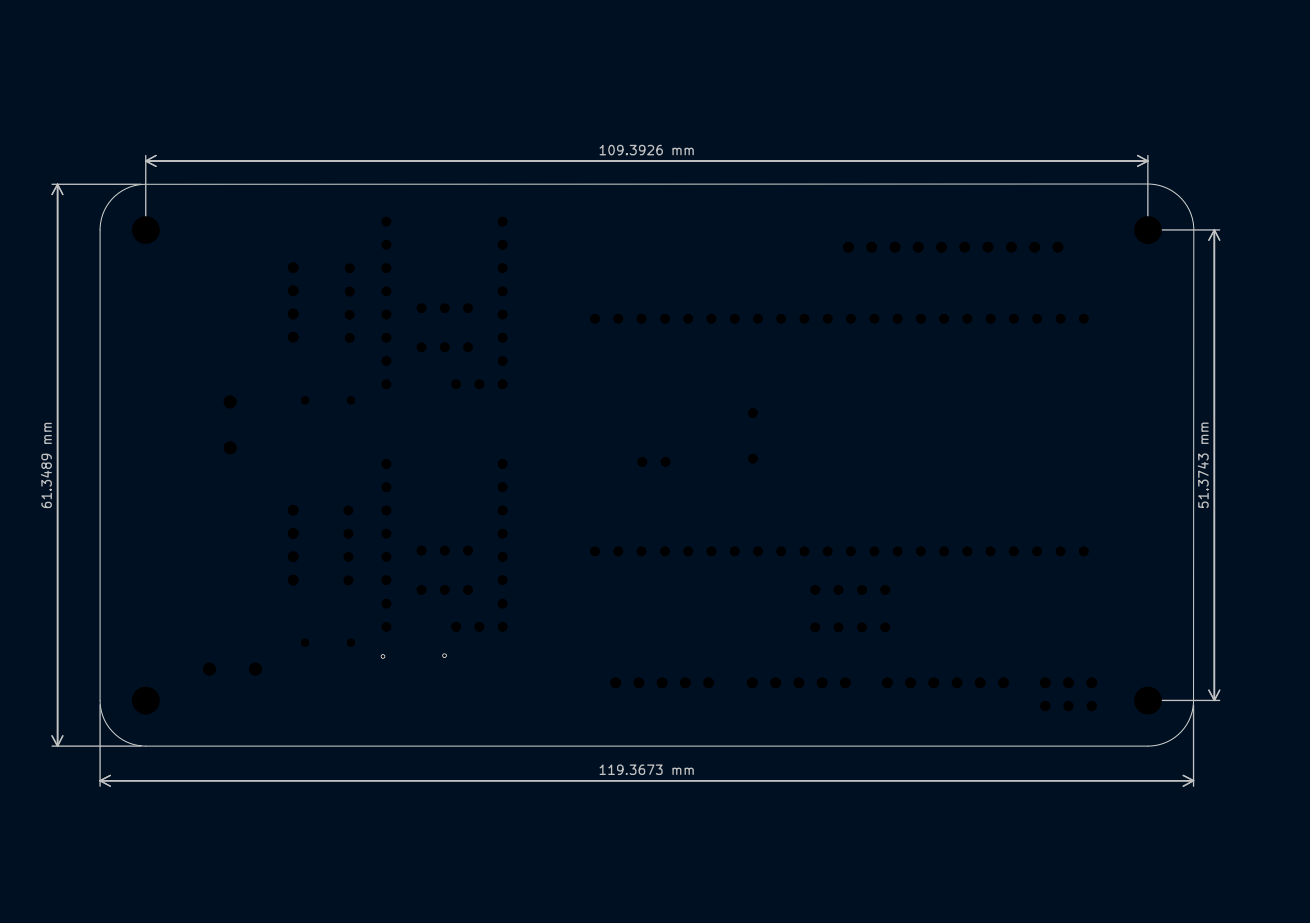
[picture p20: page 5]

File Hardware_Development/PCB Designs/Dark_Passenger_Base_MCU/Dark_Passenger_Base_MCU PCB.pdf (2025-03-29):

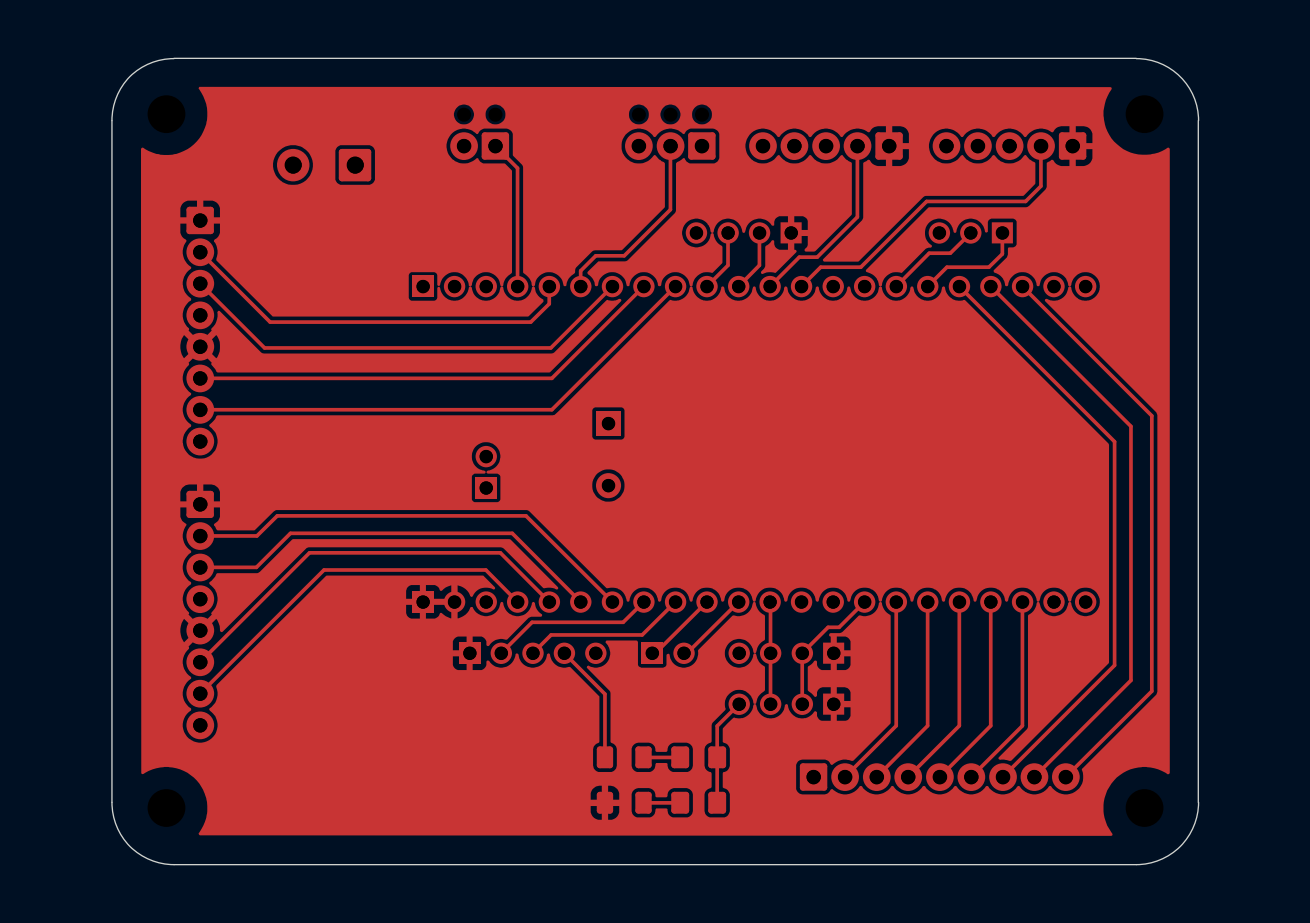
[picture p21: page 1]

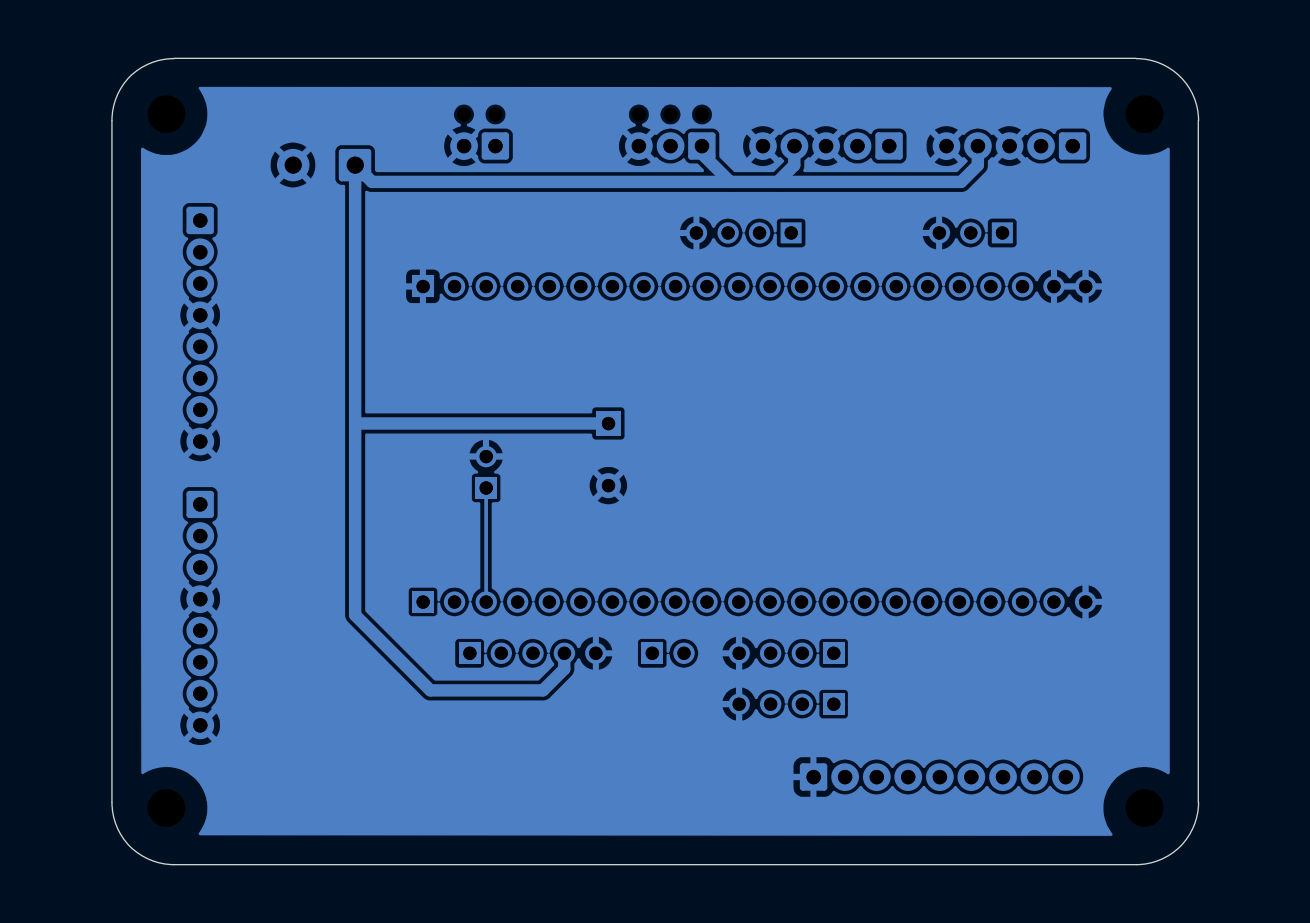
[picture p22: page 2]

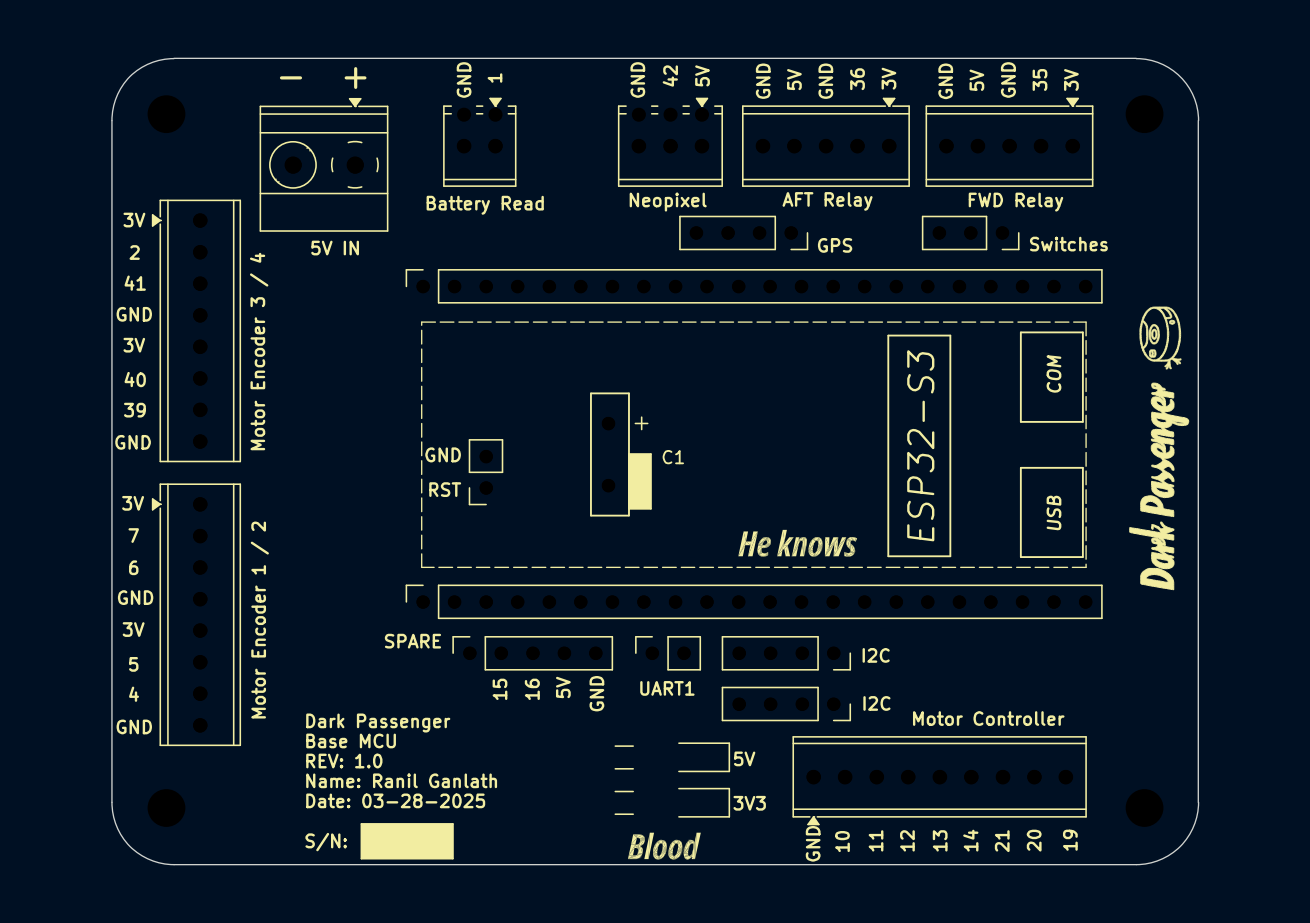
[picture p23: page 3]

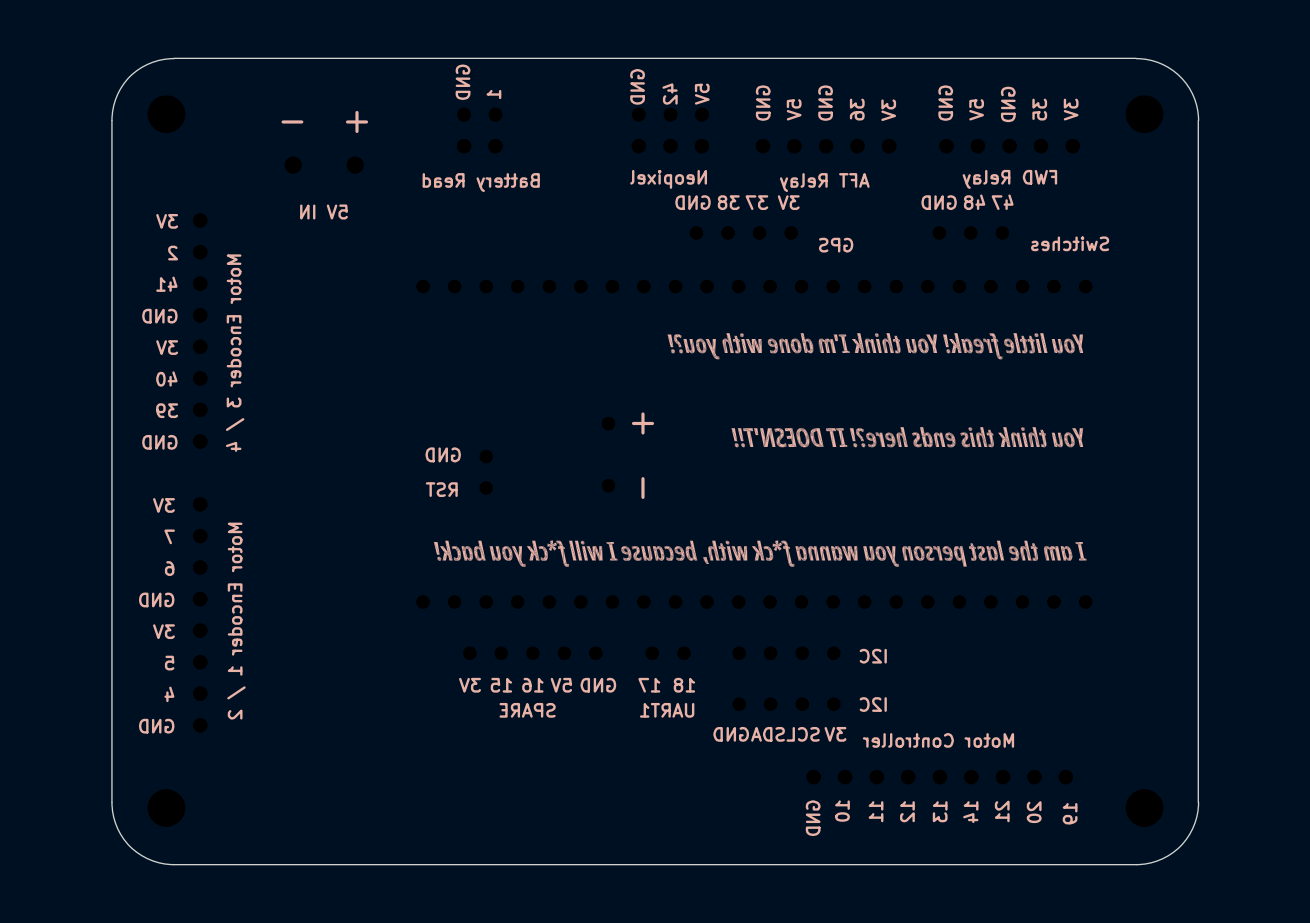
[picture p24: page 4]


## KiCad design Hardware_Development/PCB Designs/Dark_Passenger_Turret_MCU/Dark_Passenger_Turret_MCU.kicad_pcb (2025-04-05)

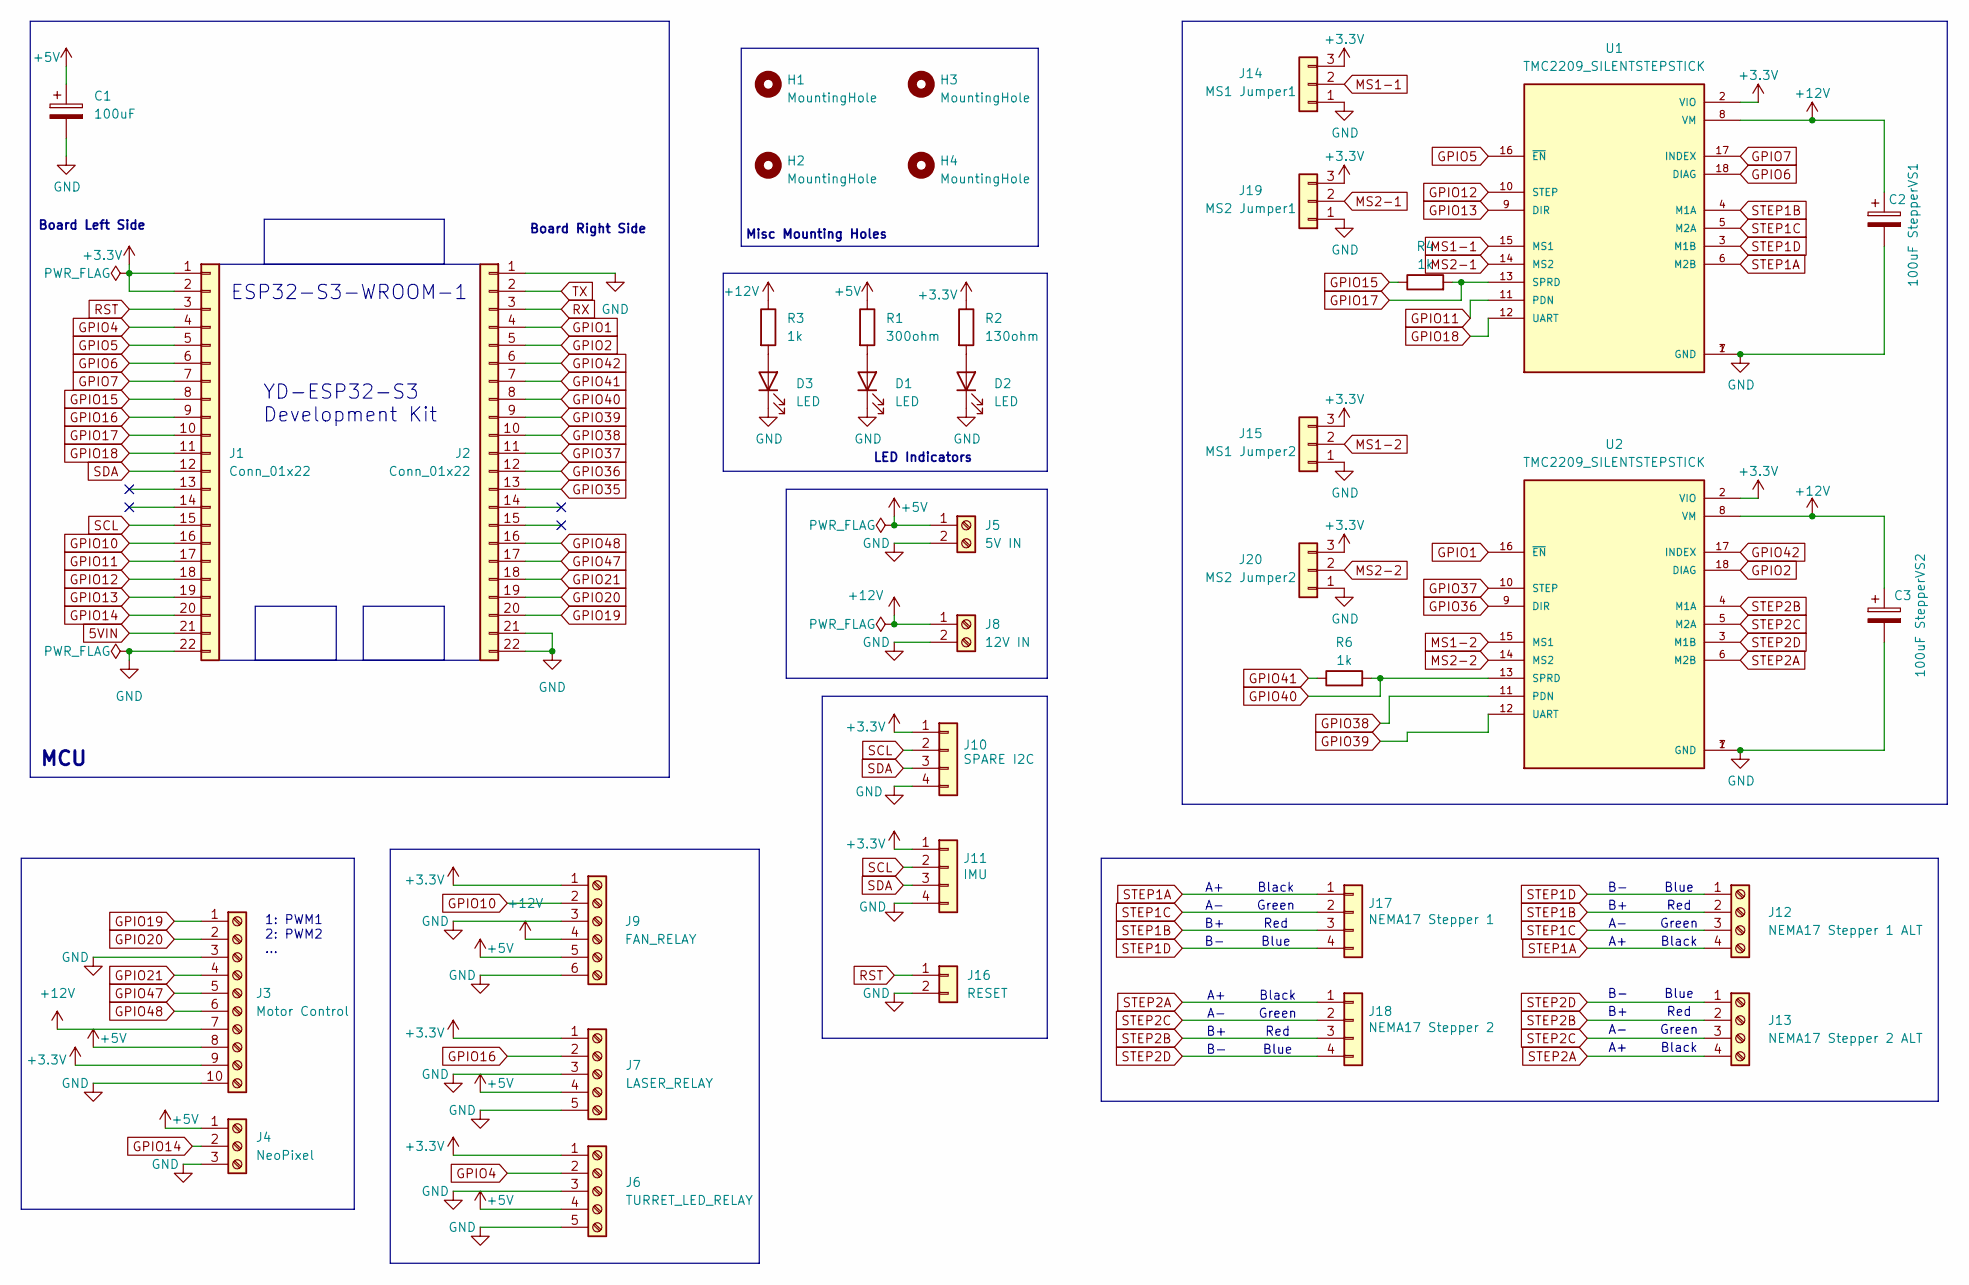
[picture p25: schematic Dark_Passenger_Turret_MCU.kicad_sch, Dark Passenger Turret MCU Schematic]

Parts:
C1: 100uF; CP_Radial_D10.0mm_P5.00mm
C2: 100uF StepperVS1; CP_Radial_D8.0mm_P5.00mm
C3: 100uF StepperVS2; CP_Radial_D8.0mm_P5.00mm
D1, D2, D3: LED; LED_1206_3216Metric_Pad1.42x1.75mm_HandSolder
H1, H2, H3, H4: MountingHole; MountingHole_3mm
J1, J2: Conn_01x22; PinSocket_1x22_P2.54mm_Vertical
J3: Motor Control; TerminalBlock_Phoenix_MPT-0,5-10-2.54_1x10_P2.54mm_Horizont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
J4: NeoPixel; TerminalBlock_Phoenix_MPT-0,5-3-2.54_1x03_P2.54mm_Horizontal
J5: 5V IN; TerminalBlock_Phoenix_MKDS-1,5-2_1x02_P5.00mm_Horizontal
J6: TURRET_LED_RELAY; TerminalBlock_Phoenix_MPT-0,5-5-2.54_1x05_P2.54mm_Horizontal
J7: LASER_RELAY; TerminalBlock_Phoenix_MPT-0,5-5-2.54_1x05_P2.54mm_Horizontal
J8: 12V IN; TerminalBlock_Phoenix_MKDS-1,5-2_1x02_P5.00mm_Horizontal
J9: FAN_RELAY; TerminalBlock_Phoenix_MPT-0,5-6-2.54_1x06_P2.54mm_Horizontal
J10: SPARE I2C; PinSocket_1x04_P2.54mm_Vertical
J11: IMU; PinSocket_1x04_P2.54mm_Vertical
J12: NEMA17 Stepper 1 ALT; TerminalBlock_Phoenix_MPT-0,5-4-2.54_1x04_P2.54mm_Horizontal
J13: NEMA17 Stepper 2 ALT; TerminalBlock_Phoenix_MPT-0,5-4-2.54_1x04_P2.54mm_Horizontal
J14: MS1 Jumper1; PinHeader_1x03_P2.54mm_Vertical
J15: MS1 Jumper2; PinHeader_1x03_P2.54mm_Vertical
J16: RESET; PinSocket_1x02_P2.54mm_Vertical
J17: NEMA17 Stepper 1; PinSocket_1x04_P2.54mm_Vertical
J18: NEMA17 Stepper 2; PinSocket_1x04_P2.54mm_Vertical
J19: MS2 Jumper1; PinHeader_1x03_P2.54mm_Vertical
J20: MS2 Jumper2; PinHeader_1x03_P2.54mm_Vertical
R1: 300ohm; R_1206_3216Metric_Pad1.30x1.75mm_HandSolder
R2: 130ohm; R_1206_3216Metric_Pad1.30x1.75mm_HandSolder
R3, R4, R6: 1k; R_1206_3216Metric_Pad1.30x1.75mm_HandSolder
U1, U2: TMC2209_SILENTSTEPSTICK; MODULE_TMC2209_SILENTSTEPSTICK; PARTREV 1.20

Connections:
5VIN: J1.21
+3.3V: J1.1, J1.2, J3.9, J6.1, J7.1, J9.1, J10.1, J11.1, J14.3, J15.3, J19.3, J20.3, R2.1, U1.2 (VIO), U2.2 (VIO)
+5V: C1.1, J3.8, J4.1, J5.1, J6.4, J7.4, J9.5, R1.1
+12V: C2.1, C3.1, J3.7, J8.1, J9.4, R3.1, U1.8 (VM), U2.8 (VM)
GND: C1.2, C2.2, C3.2, D1.1 (K), D2.1 (K), D3.1 (K), J1.22, J2.1, J2.21, J2.22, J3.3, J3.10, J4.3, J5.2, J6.3, J6.5, J7.3, J7.5, J8.2, J9.3, J9.6, J10.4, J11.4, J14.1, J15.1, J16.2, J19.1, J20.1, U1.1 (GND), U1.7 (GND), U2.1 (GND), U2.7 (GND)
GPIO1: J2.4, U2.16 (~EN)
GPIO2: J2.5, U2.18 (DIAG)
GPIO4: J1.4, J6.2
GPIO5: J1.5, U1.16 (~EN)
GPIO6: J1.6, U1.18 (DIAG)
GPIO7: J1.7, U1.17 (INDEX)
GPIO10: J1.16, J9.2
GPIO11: J1.17, U1.11 (PDN)
GPIO12: J1.18, U1.10 (STEP)
GPIO13: J1.19, U1.9 (DIR)
GPIO14: J1.20, J4.2
GPIO15: J1.8, R4.1
GPIO16: J1.9, J7.2
GPIO17: J1.10, R4.2, U1.13 (SPRD)
GPIO18: J1.11, U1.12 (UART)
GPIO19: J2.20, J3.1
GPIO20: J2.19, J3.2
GPIO21: J2.18, J3.4
GPIO35: J2.13
GPIO36: J2.12, U2.9 (DIR)
GPIO37: J2.11, U2.10 (STEP)
GPIO38: J2.10, U2.11 (PDN)
GPIO39: J2.9, U2.12 (UART)
GPIO40: J2.8, R6.2, U2.13 (SPRD)
GPIO41: J2.7, R6.1
GPIO42: J2.6, U2.17 (INDEX)
GPIO47: J2.17, J3.5
GPIO48: J2.16, J3.6
MS1-1: J14.2, U1.15 (MS1)
MS1-2: J15.2, U2.15 (MS1)
MS2-1: J19.2, U1.14 (MS2)
MS2-2: J20.2, U2.14 (MS2)
unnamed: D1.2 (A), R1.2
unnamed: D2.2 (A), R2.2
unnamed: D3.2 (A), R3.2
RST: J1.3, J16.1
RX: J2.3
SCL: J1.15, J10.2, J11.2
SDA: J1.12, J10.3, J11.3
STEP1A: J12.4, J17.1, U1.6 (M2B)
STEP1B: J12.2, J17.3, U1.4 (M1A)
STEP1C: J12.3, J17.2, U1.5 (M2A)
STEP1D: J12.1, J17.4, U1.3 (M1B)
STEP2A: J13.4, J18.1, U2.6 (M2B)
STEP2B: J13.2, J18.3, U2.4 (M1A)
STEP2C: J13.3, J18.2, U2.5 (M2A)
STEP2D: J13.1, J18.4, U2.3 (M1B)
TX: J2.2

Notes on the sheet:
Red
Blue
Misc Mounting Holes
ESP32-S3-WROOM-1
Black
Board Right Side
MCU
LED Indicators
Green
Board Left Side
1: PWM1 2: PWM2 ...
YD-ESP32-S3 Development Kit

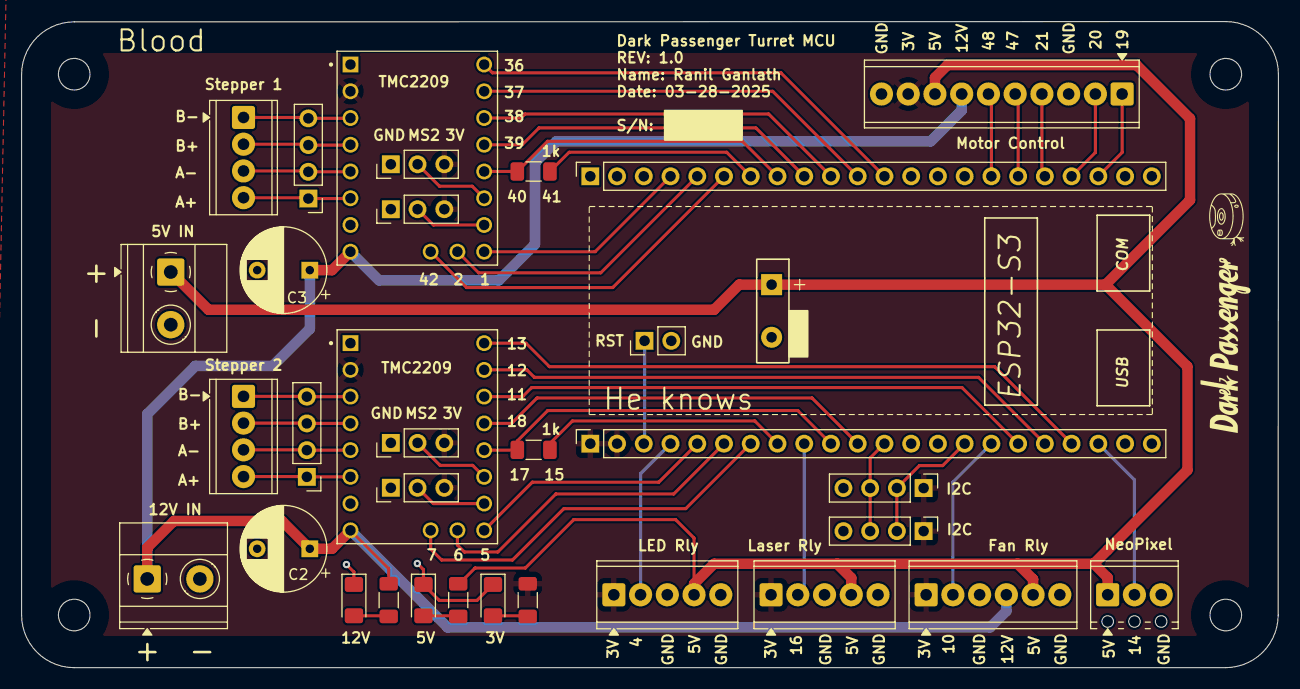
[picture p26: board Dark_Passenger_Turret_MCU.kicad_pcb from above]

Board: 2 copper layers, 119.4 x 61.4 mm, 37 parts (0 on the bottom side), 49 nets.

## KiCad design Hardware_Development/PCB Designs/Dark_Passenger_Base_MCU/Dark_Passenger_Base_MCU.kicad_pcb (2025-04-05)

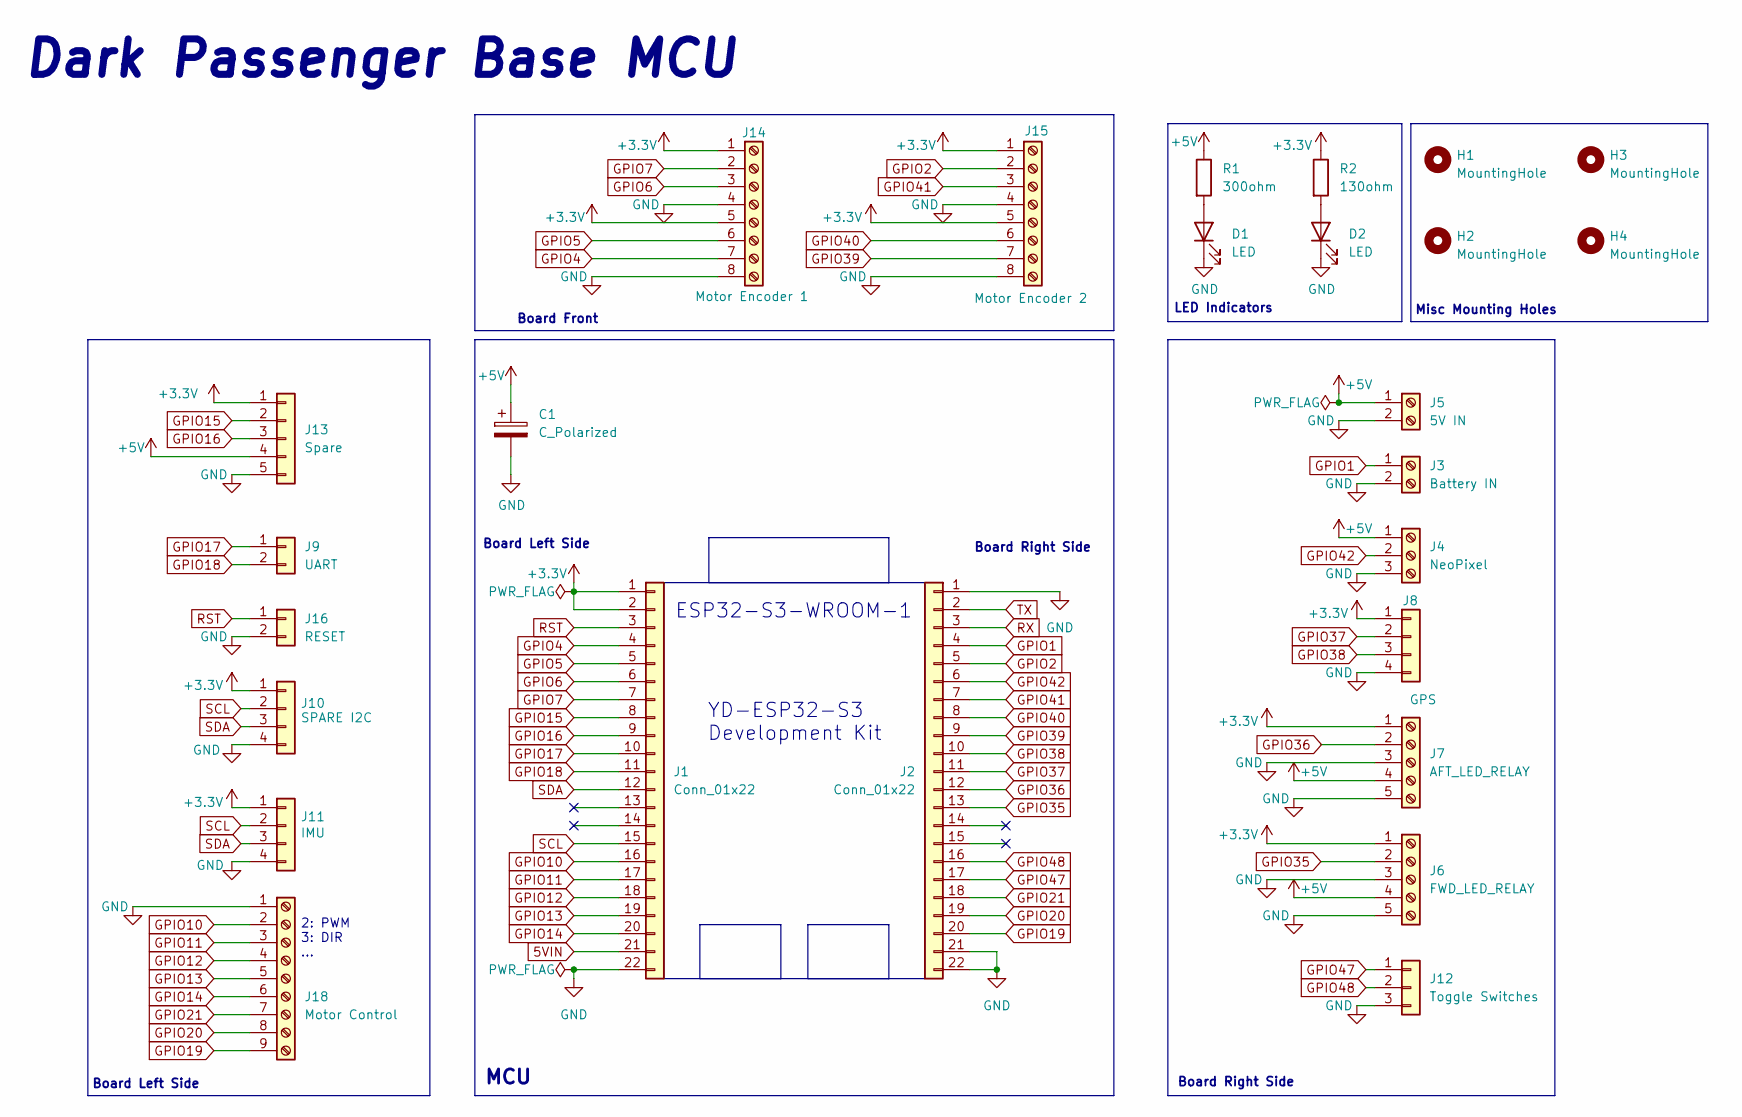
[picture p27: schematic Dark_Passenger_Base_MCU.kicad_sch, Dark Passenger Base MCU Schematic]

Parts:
C1: C_Polarized; CP_Radial_D10.0mm_P5.00mm
D1, D2: LED; LED_1206_3216Metric_Pad1.42x1.75mm_HandSolder
H1, H2, H3, H4: MountingHole; MountingHole_3mm
J1, J2: Conn_01x22; PinSocket_1x22_P2.54mm_Vertical
J3: Battery IN; TerminalBlock_Phoenix_MPT-0,5-2-2.54_1x02_P2.54mm_Horizontal
J4: NeoPixel; TerminalBlock_Phoenix_MPT-0,5-3-2.54_1x03_P2.54mm_Horizontal
J5: 5V IN; TerminalBlock_Phoenix_MKDS-1,5-2_1x02_P5.00mm_Horizontal
J6: FWD_LED_RELAY; TerminalBlock_Phoenix_MPT-0,5-5-2.54_1x05_P2.54mm_Horizontal
J7: AFT_LED_RELAY; TerminalBlock_Phoenix_MPT-0,5-5-2.54_1x05_P2.54mm_Horizontal
J8: GPS; PinSocket_1x04_P2.54mm_Vertical
J9: UART; PinSocket_1x02_P2.54mm_Vertical
J10: SPARE I2C; PinSocket_1x04_P2.54mm_Vertical
J11: IMU; PinSocket_1x04_P2.54mm_Vertical
J12: Toggle Switches; PinSocket_1x03_P2.54mm_Vertical
J13: Spare; PinSocket_1x05_P2.54mm_Vertical
J14: Motor Encoder 1; TerminalBlock_Phoenix_MPT-0,5-8-2.54_1x08_P2.54mm_Horizontal
J15: Motor Encoder 2; TerminalBlock_Phoenix_MPT-0,5-8-2.54_1x08_P2.54mm_Horizontal
J16: RESET; PinSocket_1x02_P2.54mm_Vertical
J18: Motor Control; TerminalBlock_Phoenix_MPT-0,5-9-2.54_1x09_P2.54mm_Horizontal
R1: 300ohm; R_1206_3216Metric_Pad1.30x1.75mm_HandSolder
R2: 130ohm; R_1206_3216Metric_Pad1.30x1.75mm_HandSolder

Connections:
5VIN: J1.21
+3.3V: J1.1, J1.2, J6.1, J7.1, J8.1, J10.1, J11.1, J13.1, J14.1, J14.5, J15.1, J15.5, R2.1
+5V: C1.1, J4.1, J5.1, J6.4, J7.4, J13.4, R1.1
GND: C1.2, D1.1 (K), D2.1 (K), J1.22, J2.1, J2.21, J2.22, J3.2, J4.3, J5.2, J6.3, J6.5, J7.3, J7.5, J8.4, J10.4, J11.4, J12.3, J13.5, J14.4, J14.8, J15.4, J15.8, J16.2, J18.1
GPIO1: J2.4, J3.1
GPIO2: J2.5, J15.2
GPIO4: J1.4, J14.7
GPIO5: J1.5, J14.6
GPIO6: J1.6, J14.3
GPIO7: J1.7, J14.2
GPIO10: J1.16, J18.2
GPIO11: J1.17, J18.3
GPIO12: J1.18, J18.4
GPIO13: J1.19, J18.5
GPIO14: J1.20, J18.6
GPIO15: J1.8, J13.2
GPIO16: J1.9, J13.3
GPIO17: J1.10, J9.1
GPIO18: J1.11, J9.2
GPIO19: J2.20, J18.9
GPIO20: J2.19, J18.8
GPIO21: J2.18, J18.7
GPIO35: J2.13, J6.2
GPIO36: J2.12, J7.2
GPIO37: J2.11, J8.2
GPIO38: J2.10, J8.3
GPIO39: J2.9, J15.7
GPIO40: J2.8, J15.6
GPIO41: J2.7, J15.3
GPIO42: J2.6, J4.2
GPIO47: J2.17, J12.1
GPIO48: J2.16, J12.2
unnamed: D1.2 (A), R1.2
unnamed: D2.2 (A), R2.2
RST: J1.3, J16.1
RX: J2.3
SCL: J1.15, J10.2, J11.2
SDA: J1.12, J10.3, J11.3
TX: J2.2

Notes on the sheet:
Board Right Side
Board Front
Misc Mounting Holes
ESP32-S3-WROOM-1
Board Left Side
MCU
Dark Passenger Base MCU
LED Indicators
2: PWM 3: DIR ...
YD-ESP32-S3 Development Kit

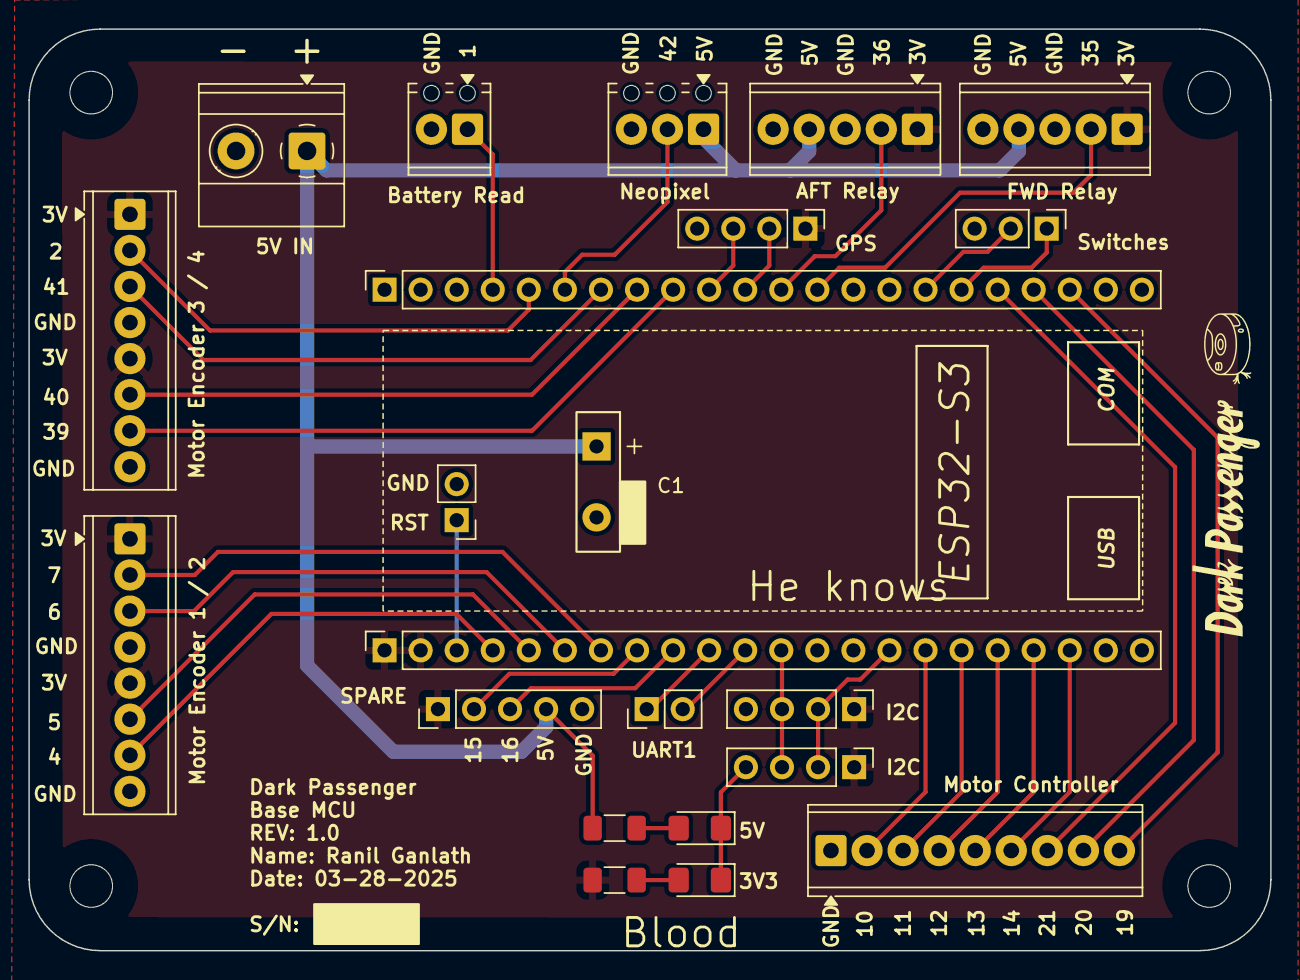
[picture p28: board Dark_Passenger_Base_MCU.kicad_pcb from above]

Board: 2 copper layers, 87.5 x 64.9 mm, 26 parts (0 on the bottom side), 36 nets.

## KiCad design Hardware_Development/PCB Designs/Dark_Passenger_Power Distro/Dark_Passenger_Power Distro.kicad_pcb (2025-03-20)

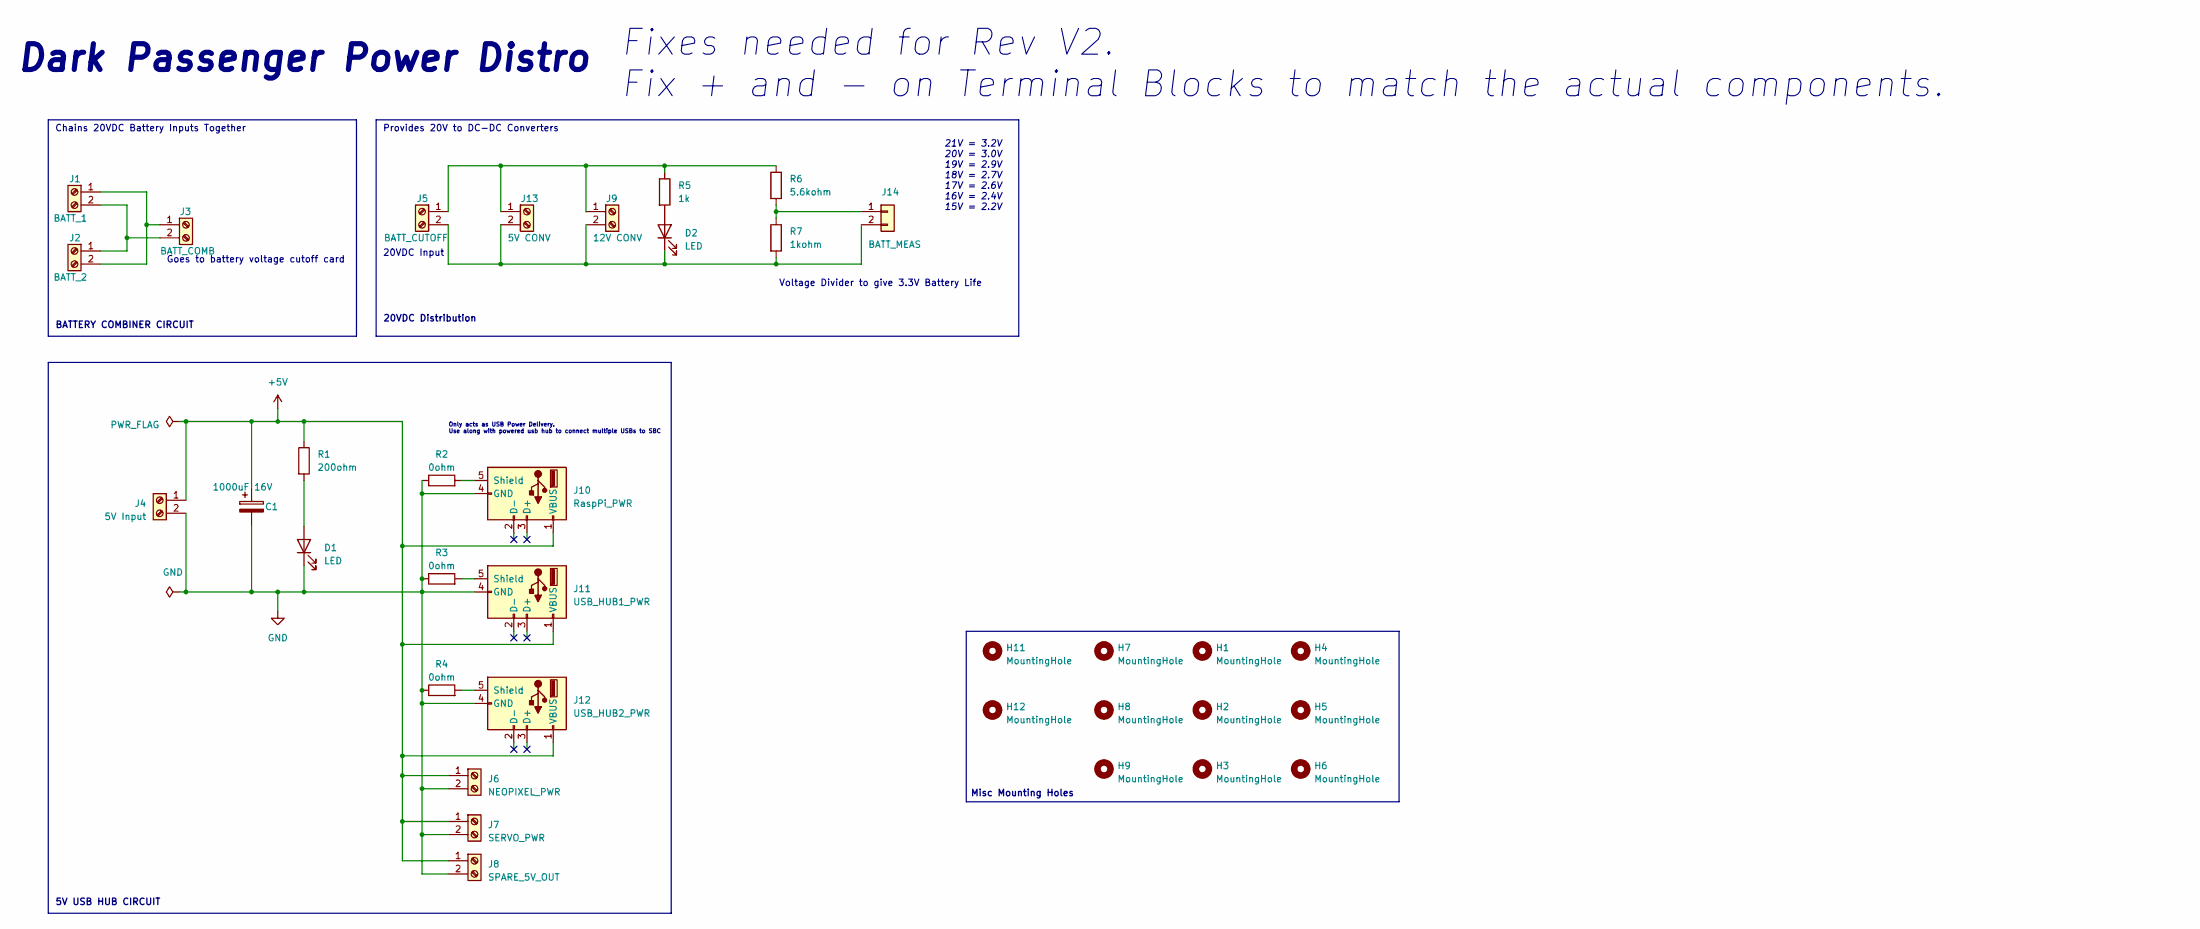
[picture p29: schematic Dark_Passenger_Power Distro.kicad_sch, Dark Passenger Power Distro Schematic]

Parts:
C1: 1000uF 16V; C_Radial_D10.0mm_H16.0mm_P5.00mm
D1, D2: LED; LED_1206_3216Metric_Pad1.42x1.75mm_HandSolder
H1, H2, H3, H4, H5, H6, H7, H8, H9, H11, H12: MountingHole; MountingHole_3mm
J1: BATT_1; TerminalBlock_Phoenix_MKDS-1,5-2_1x02_P5.00mm_Horizontal
J2: BATT_2; TerminalBlock_Phoenix_MKDS-1,5-2_1x02_P5.00mm_Horizontal
J3: BATT_COMB; TerminalBlock_Phoenix_MKDS-1,5-2_1x02_P5.00mm_Horizontal
J4: 5V Input; TerminalBlock_Phoenix_MKDS-1,5-2_1x02_P5.00mm_Horizontal
J5: BATT_CUTOFF; TerminalBlock_Phoenix_MKDS-1,5-2_1x02_P5.00mm_Horizontal
J6: NEOPIXEL_PWR; TerminalBlock_Phoenix_MKDS-1,5-2_1x02_P5.00mm_Horizontal
J7: SERVO_PWR; TerminalBlock_Phoenix_MKDS-1,5-2_1x02_P5.00mm_Horizontal
J8: SPARE_5V_OUT; TerminalBlock_Phoenix_MKDS-1,5-2_1x02_P5.00mm_Horizontal
J9: 12V CONV; TerminalBlock_Phoenix_MKDS-1,5-2_1x02_P5.00mm_Horizontal
J10: RaspPi_PWR; USB_A_Molex_67643_Horizontal
J11: USB_HUB1_PWR; USB_A_Molex_67643_Horizontal
J12: USB_HUB2_PWR; USB_A_Molex_67643_Horizontal
J13: 5V CONV; TerminalBlock_Phoenix_MKDS-1,5-2_1x02_P5.00mm_Horizontal
J14: BATT_MEAS; PinHeader_1x02_P2.54mm_Vertical
R1: 200ohm; R_1206_3216Metric_Pad1.30x1.75mm_HandSolder
R2, R3, R4: 0ohm; R_1206_3216Metric_Pad1.30x1.75mm_HandSolder
R5: 1k; R_1206_3216Metric_Pad1.30x1.75mm_HandSolder
R6: 5.6kohm; R_1206_3216Metric_Pad1.30x1.75mm_HandSolder
R7: 1kohm; R_1206_3216Metric_Pad1.30x1.75mm_HandSolder

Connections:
+5V: C1.1, J4.1, J6.1, J7.1, J8.1, J10.1 (VBUS), J11.1 (VBUS), J12.1 (VBUS), R1.1
GND: C1.2, D1.1 (K), J4.2, J6.2, J7.2, J8.2, J10.4 (GND), J11.4 (GND), J12.4 (GND), R2.1, R3.1, R4.1
unnamed: D1.2 (A), R1.2
unnamed: D2.2 (A), R5.2
unnamed: D2.1 (K), J5.2, J9.2, J13.2, J14.2, R7.2
unnamed: J1.1, J2.2, J3.1
unnamed: J1.2, J2.1, J3.2
unnamed: J10.5 (Shield), R2.2
unnamed: J11.5 (Shield), R3.2
unnamed: J12.5 (Shield), R4.2
unnamed: J5.1, J9.1, J13.1, R5.1, R6.1
unnamed: J14.1, R6.2, R7.1

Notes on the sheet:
Fixes needed for Rev V2. Fix + and - on Terminal Blocks to match the actual components.
20VDC Distribution
5V USB HUB CIRCUIT
Misc Mounting Holes
21V = 3.2V 20V = 3.0V 19V = 2.9V 18V = 2.7V 17V = 2.6V 16V = 2.4V 15V = 2.2V
Voltage Divider to give 3.3V Battery Life
20VDC Input
Dark Passenger Power Distro
Chains 20VDC Battery Inputs Together
Only acts as USB Power Delivery. Use along with powered usb hub to connect multiple USBs to SBC
Goes to battery voltage cutoff card
BATTERY COMBINER CIRCUIT
Provides 20V to DC-DC Converters

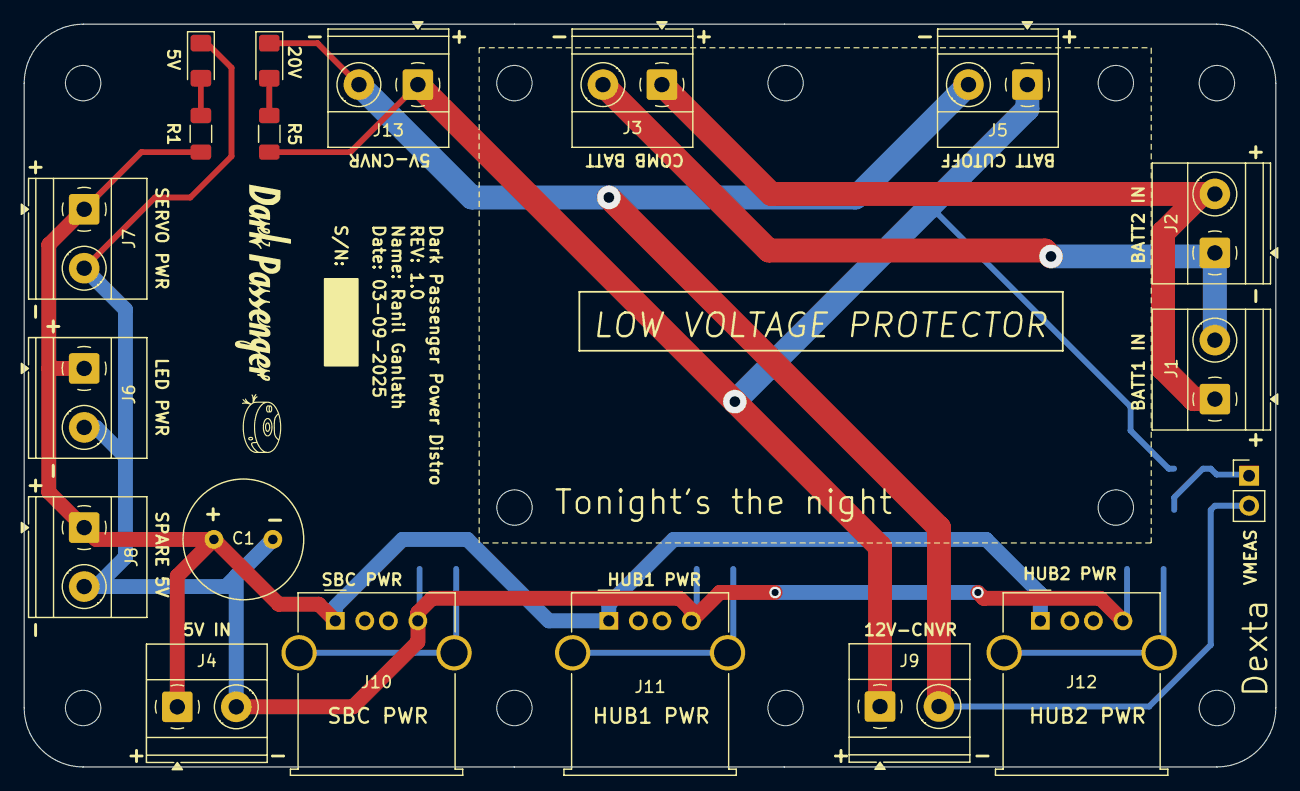
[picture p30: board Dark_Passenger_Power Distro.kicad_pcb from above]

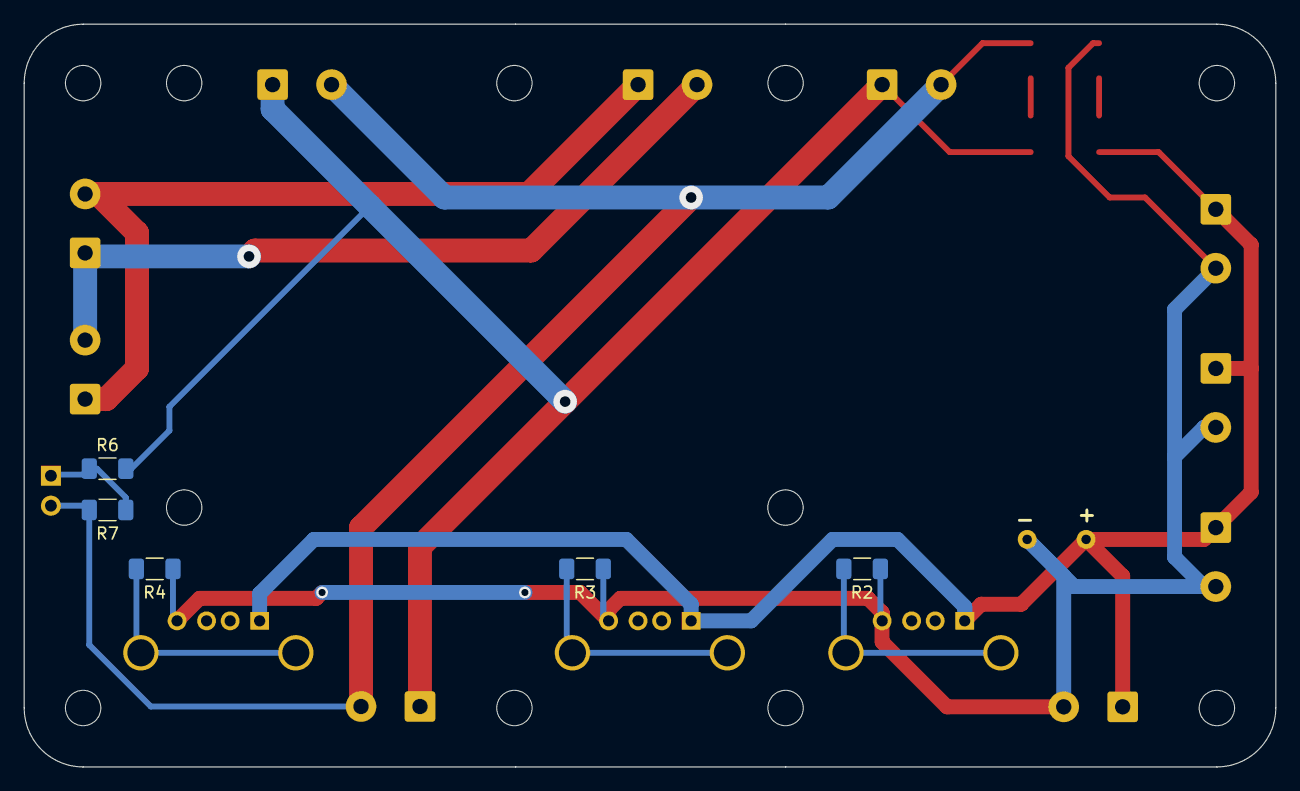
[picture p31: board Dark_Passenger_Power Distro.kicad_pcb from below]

Board: 2 copper layers, 106.2 x 63.0 mm, 35 parts (5 on the bottom side), 12 nets.

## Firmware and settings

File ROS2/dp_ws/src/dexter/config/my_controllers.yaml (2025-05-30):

controller_manager:
  ros__parameters:
    update_rate: 30
    # use_sim_time: true

    diff_cont:
      type: diff_drive_controller/DiffDriveController

    joint_broad:
      type: joint_state_broadcaster/JointStateBroadcaster

diff_cont:
  ros__parameters:

    publish_rate: 50.0

    base_frame_id: base_link

    left_wheel_names: ['left_wheel_joint']
    right_wheel_names: ['right_wheel_joint']
    wheel_separation: 0.218
    wheel_radius: 0.035

    #use_stamped_vel: false

    # open_loop: false    

    # wheels_per_side: x
    # wheel_separation_multiplier: x
    # left_wheel_radius_multiplier: x
    # right_wheel_radius_multiplier: x

    # odom_frame_id: x
    # pose_covariance_diagonal: x
    # twist_covariance_diagonal: x
    # open_loop: x
    # enable_odom_tf: x

    # cmd_vel_timeout: x
    # publish_limited_velocity: x
    # velocity_rolling_window_size: x
    

    # linear.x.has_velocity_limits: false
    # linear.x.has_acceleration_limits: false
    # linear.x.has_jerk_limits: false
    # linear.x.max_velocity: NAN
    # linear.x.min_velocity: NAN
    # linear.x.max_acceleration: NAN
    # linear.x.min_acceleration: NAN
    # linear.x.max_jerk: NAN
    # linear.x.min_jerk: NAN

    # angular.z.has_velocity_limits: false
    # angular.z.has_acceleration_limits: false
    # angular.z.has_jerk_limits: false
    # angular.z.max_velocity: NAN
    # angular.z.min_velocity: NAN
    # angular.z.max_acceleration: NAN
    # angular.z.min_acceleration: NAN
    # angular.z.max_jerk: NAN
    # angular.z.min_jerk: NAN




# joint_broad:
#   ros__parameters:

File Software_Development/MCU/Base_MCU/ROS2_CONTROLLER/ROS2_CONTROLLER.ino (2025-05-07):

/*
  By Ranil Ganlath (Modified for ROS2 Communication)
  This script is for adapting the Serial Controller to be in a format for sending and receiving ROS2 serial messages.
  The Dark Passenger ROS2 Controller expects a command along with chunks of data like floats, text, etc. The data notation is "<CMD,value_1,value_2,...value_n>. Ex. <M,80,80> which sets the motor velocities for both wheels to 80 speed.

  ESP32 1  - Battery Input Pin (from 0 to 3.3V)
  ESP32 47  - Toggle Switch 1
  ESP32 48  - Toggle Switch 2 (Not working, ESP32 might be damaged since wiring is good)
  ESP32 35  - Relay FWD Headlight Control Output
  ESP32 36  - Relay AFT Brake Light Control Output
  ESP32 8  -  IMS I2C SDA
  ESP32 9  -  IMS I2C SCL
  ESP32 38  - GPS RX Input (routes to TX)
  ESP32 37  - GPS TX Output (routes to RX)
  ESP32 GND - Motor Driver GND
  ESP32 11  - Motor Driver PWM 1 Input
  ESP32 13  - Motor Driver DIR 1 Input
  ESP32 21  - Motor Driver PWM 2 Input
  ESP32 19  - Motor Driver DIR 2 Input
  
  IDE Configuration:
  Arduino Board: ESP32S3 Dev Module
  Upload Speed: 921600
  USB Mode: Hardware CDC and JTAG
  USB CDC On Boot: Disabled
  USB Firmware MSC On Boot: Disabled
  USB DFU On Boot: Disabled
  Upload Mode: UART0/Hardware CDC
  CPU Freq: 240MHz
  Flash Mode: QIO 80MHz
  Flash Size: 4MB
  Parition Scheme: Default 4MB with spiffs
  Core Debug Level: None
  PSRAM: Disabled
  Arduino Runs On: Core 1
  Events Run On: Core 1
  Erash All Flash Before Sketch Upload: Disabled
  JTAG Adapter: Disabled
  Zigbee Mode: Disabled
*/

// Pin definitions
#define BATTERY_MONITOR_PIN 1
#define TOGGLE_SW1_PIN 47
#define TOGGLE_SW2_PIN 48 //not working
#define FWD_RELAY_CTRL_PIN 35
#define AFT_RELAY_CTRL_PIN 36
#define NEOPIXEL_PIN 48 //pin 42 is neopixel breakout pin.
#define IMS_SDA_PIN 8
#define IMS_SCL_PIN 9
#define GPS_RX_PIN 38
#define GPS_TX_PIN 37
#define MOTOR_DRIVER_PWM1_PIN 11
#define MOTOR_DRIVER_DIR1_PIN 13
#define MOTOR_DRIVER_PWM2_PIN 21
#define MOTOR_DRIVER_DIR2_PIN 19
#define LEFT_ENC_PIN 41
#define RIGHT_ENC_PIN 6
#define LEFT_WHEEL_SW_PIN 40
#define RIGHT_WHEEL_SW_PIN 5

// Motor speed constants
#define MAX_MOTOR_SPEED 100  // Maximum PWM value
#define MOTOR_SPEED 100      // Standard movement speed (25% of max)

// Encoder parameters
#define TRANSITIONS_PER_REV 508.8  // 8 transitions × 63.6:1 gear ratio
#define WHEEL_DIAMETER_MM 70.0     // Roomba wheel diameter in mm (adjust if different)
#define PI 3.14159265359

// ROS2 Communication Parameters
#define SERIAL_BAUD_RATE 115200
#define MSG_START_MARKER '<'
#define MSG_END_MARKER '>'
#define MSG_SEPARATOR ','
#define PUBLISH_INTERVAL 200     // Publish sensor data every 200ms

// ROS2 Command IDs
#define CMD_MOVE 'M'          // Format: <M,speed_left,speed_right>
#define CMD_LIGHTS 'L'        // Format: <L,headlight,brakelight> (0=off, 1=on)
#define CMD_RESET_ENC 'R'     // Format: <R> - Reset encoders
#define CMD_HEARTBEAT 'H'     // Format: <H> - Triggers MSG_Start, Responds with <K,1>


// ROS2 Sensor Message Types
#define MSG_START 'K'         // Format: <K,1>
#define MSG_ODOM 'O'          // Format: <O,left_dist,right_dist,left_count,right_count>
#define MSG_BATTERY 'B'       // Format: <B,voltage,percentage>
#define MSG_IMU 'I'           // Format: <I,aX,aY,aZ,gX,gY,gZ,mX,mY,mZ,heading>
#define MSG_GPS 'G'           // Format: <G,lat,lng,satellites,valid>
#define MSG_STATUS 'S'        // Format: <S,sw1,sw2,wheel1_sw,wheel2_sw,headlight,brakelight>

//Configure GPS
#define GPS_BAUD 9600
HardwareSerial gpsSerial(2);


// class for computing motor control signal
class SimplePID {
  private:
    float kp, kd, ki, umax; //Params for pid gains and max motor speed
    float eprev, eintegral; //Storage for derivative and integral from prior loop
  public:
    //Constructor
    SimplePID(): kp(1.0), kd(0), ki(0), umax(255), eprev(0.0), eintegral(0.0) {}
    //Function to set params
    void setParams(float kpIn, float kdIn, float kiIn, float umaxIn) {
      kp = kpIn; kd = kdIn; ki = kiIn; umax = umaxIn;
    }
    //compute the control signal
    void evalu(float value, float target, float deltaT, int &pwr, int &dir) {
      //this is the equation we are trying to solve: u(t) = Kp*e(t) + Ki* integral(e(t)*dt) + Kd* de/dt
      //Kp is proportial gain, Ki is integral gain, Kd is derivative gain
      //e(t) is the error value, de is the change in error value, dt is change in time
      //We solve for u(t) which is the PID control variable which converts to motor speed and direction
      //error
      float e = target - value;
      //derivative
      float dedt = (e - eprev) / (deltaT); //change in error over change in time
      //integral
      eintegral = eintegral + e * deltaT;
      //control signal
      float u = kp * e + kd * dedt + ki * eintegral;
      //motor power
      pwr = (int) fabs(u); //take magnitude and store in pointer
      if ( pwr > umax ) { //boundary check
        pwr = umax;
      }
      //motor direction
      dir = 1;
      if (u < 0) {
        dir = -1;
      }
      //store previous value of error
      eprev = e;
    }
    
    // Reset the controller's integral and previous error terms
    void reset() {
      eprev = 0.0;
      eintegral = 0.0;
    }
};


//Import Libraries
#include "CytronMotorDriver.h"
#include <TinyGPSPlus.h>
#include <MPU9250_asukiaaa.h>

//Configure GPS
TinyGPSPlus gps;
const int timeZoneOffset = -6;

//Configure IMS MPU9250
MPU9250_asukiaaa mySensor;
float aX, aY, aZ, aSqrt, gX, gY, gZ, mDirection, mX, mY, mZ;

// Configure the motor driver.
CytronMD motor1(PWM_DIR, MOTOR_DRIVER_PWM1_PIN, MOTOR_DRIVER_DIR1_PIN);
CytronMD motor2(PWM_DIR, MOTOR_DRIVER_PWM2_PIN, MOTOR_DRIVER_DIR2_PIN);

// Motor direction adjustment if needed (set to -1 if motor runs in the opposite direction)
const int LEFT_MOTOR_DIRECTION = -1;   // Change to -1 if left motor runs backward
const int RIGHT_MOTOR_DIRECTION = -1;  // Change to -1 if right motor runs backward


// Encoder tracking variables
volatile unsigned long leftEncoderCount = 0;
volatile unsigned long rightEncoderCount = 0;
int lastLeftState = 0;
int lastRightState = 0;

// Timing variables
unsigned long lastUpdateTime = 0;
unsigned long lastPublishTime = 0;
unsigned long lastPIDUpdateTime = 0;
const unsigned long UPDATE_INTERVAL = 100; // Update every 100ms
const unsigned long PID_UPDATE_INTERVAL = 20; // PID update every 20ms for smoother control

// Distance tracking
float leftDistanceMM = 0.0;
float rightDistanceMM = 0.0;

// Velocity tracking
float leftVelocity = 0.0;  // mm/s
float rightVelocity = 0.0; // mm/s
unsigned long prevLeftCount = 0;
unsigned long prevRightCount = 0;
unsigned long velocityUpdateTime = 0;

// Target velocity variables
float leftTargetVelocity = 0.0;  // mm/s
float rightTargetVelocity = 0.0; // mm/s

// Direction tracking for velocity calculation
int lastLeftDir = 1;  // Initialize with forward direction
int lastRightDir = 1; // Initialize with forward direction

// PID controllers for left and right wheels
SimplePID leftPID;
SimplePID rightPID;

// ROS2 Communication variables
const byte numChars = 64;
char receivedChars[numChars];
boolean newData = false;
boolean receivingData = false;
byte dataIndex = 0;

//Battery Level Monitoring
int batteryVoltage = 3000; // actual battery voltage in millivolts
int batteryPercentage = 100;

//Configure Relays
bool FWD_RELAY_ON = false;
bool AFT_RELAY_ON = false;

//Configure Toggle Switches
int toggleSwitch1_state = 0;        // value read from SW1
int toggleSwitch2_state = 0;        // value read from SW2


// Function to convert raw motor speed to velocity (mm/s)
float convertSpeedToVelocity(int speed) {
  // Simple linear conversion from motor PWM to velocity
  // This is an approximation and should be calibrated for your specific robot
  // Maximum speed of 255 PWM might correspond to approximately 200 mm/s
  const float MAX_VELOCITY = 200.0; // mm/s at maximum PWM
  return (speed * MAX_VELOCITY) / MAX_MOTOR_SPEED;
}

// Function to set motor speeds with direction
void setMotorSpeed(CytronMD &motor, int power, int direction) {
  // We'll directly use the Cytron's setSpeed function which accepts values from -255 to 255
  int speed = direction * power;
  // Ensure speed doesn't exceed motor controller's limits
  speed = constrain(speed, -MAX_MOTOR_SPEED, MAX_MOTOR_SPEED);
  // Use Cytron's setSpeed which accepts negative values for reverse direction
  motor.setSpeed(speed);
}

void setup() {
  // Initialize pins
  pinMode(LEFT_ENC_PIN, INPUT_PULLUP);
  pinMode(RIGHT_ENC_PIN, INPUT_PULLUP);
  pinMode(LEFT_WHEEL_SW_PIN, INPUT_PULLUP);
  pinMode(RIGHT_WHEEL_SW_PIN, INPUT_PULLUP);
  pinMode(FWD_RELAY_CTRL_PIN, OUTPUT);
  pinMode(AFT_RELAY_CTRL_PIN, OUTPUT);
  pinMode(TOGGLE_SW1_PIN, INPUT_PULLUP);
  pinMode(TOGGLE_SW2_PIN, INPUT_PULLUP); 

  // Initialize relays (turn off)
  digitalWrite(FWD_RELAY_CTRL_PIN, LOW);
  digitalWrite(AFT_RELAY_CTRL_PIN, LOW);
  
  // Battery Monitoring
  pinMode(BATTERY_MONITOR_PIN, INPUT);
  analogReadResolution(12);
  
  // Initialize Serial Communication
  Serial.begin(SERIAL_BAUD_RATE);
  while(!Serial);

  // IMS I2C initialization
  Wire.begin(IMS_SDA_PIN, IMS_SCL_PIN);
  mySensor.setWire(&Wire);
  mySensor.beginAccel();
  mySensor.beginGyro();
  mySensor.beginMag();

  // GPS initialization
  gpsSerial.begin(GPS_BAUD, SERIAL_8N1, GPS_RX_PIN, GPS_TX_PIN);
  
  // Initialize encoder states
  lastLeftState = digitalRead(LEFT_ENC_PIN);
  lastRightState = digitalRead(RIGHT_ENC_PIN);
  
  // Initialize motors (stopped)
  motor1.setSpeed(0);
  motor2.setSpeed(0);

  // Initialize PID controllers
  // Parameters: Kp, Kd, Ki, max_output
  leftPID.setParams(1.0, 0.003, 0.006, MAX_MOTOR_SPEED);
  rightPID.setParams(1.0, 0.003, 0.006, MAX_MOTOR_SPEED);
  //Note incorporate speed-dependent tuning later

   
  // Send robot initialization complete message  
  Serial.println("<K,1>");

  // Initialize timing
  lastUpdateTime = millis();
  lastPIDUpdateTime = millis();
  velocityUpdateTime = millis();
}

void loop() {
  // Process GPS data continuously
  while (gpsSerial.available()) {
    gps.encode(gpsSerial.read());
  }

  // Check for incoming ROS2 commands
  receiveROS2Message();

  // Process new ROS2 commands
  if (newData) {
    parseAndExecuteCommand();
    newData = false;
  }

  // Read encoder states and count transitions
  int currentLeftState = digitalRead(LEFT_ENC_PIN);
  int currentRightState = digitalRead(RIGHT_ENC_PIN);
  
  // Check for left encoder transition
  if (currentLeftState != lastLeftState) {
    leftEncoderCount++;
    lastLeftState = currentLeftState;
  }
  
  // Check for right encoder transition
  if (currentRightState != lastRightState) {
    rightEncoderCount++;
    lastRightState = currentRightState;
  }

  // Update sensor readings periodically
  unsigned long currentTime = millis();
  if (currentTime - lastUpdateTime >= UPDATE_INTERVAL) {
    // Calculate distances
    leftDistanceMM = calculateDistance(leftEncoderCount);
    rightDistanceMM = calculateDistance(rightEncoderCount);
    
    // Calculate velocities (counts per second, then convert to mm/s)
    float deltaTime = (currentTime - velocityUpdateTime) / 1000.0; // Convert to seconds
    unsigned long deltaLeftCount = leftEncoderCount - prevLeftCount;
    unsigned long deltaRightCount = rightEncoderCount - prevRightCount;
    
    // Calculate raw velocity (doesn't account for direction yet)
    float rawLeftVelocity = (deltaLeftCount / TRANSITIONS_PER_REV) * PI * WHEEL_DIAMETER_MM / deltaTime;
    float rawRightVelocity = (deltaRightCount / TRANSITIONS_PER_REV) * PI * WHEEL_DIAMETER_MM / deltaTime;
    
    // We need to track the last direction commands and use them to determine velocity direction
    // If last command was negative, we assume we're moving backward
    if (lastLeftDir < 0) {
      leftVelocity = -rawLeftVelocity;
    } else {
      leftVelocity = rawLeftVelocity;
    }
    
    if (lastRightDir < 0) {
      rightVelocity = -rawRightVelocity;
    } else {
      rightVelocity = rawRightVelocity;
    }
    
    // Update previous counts and time
    prevLeftCount = leftEncoderCount;
    prevRightCount = rightEncoderCount;
    velocityUpdateTime = currentTime;
    
    // Read other sensors
    readBatteryLevel();
    readToggleSwitches();
    updateIMSData();
    
    // Update timing
    lastUpdateTime = currentTime;
  }

  // Variables to store PID outputs
  int leftPower = 0, leftDir = 0;
  int rightPower = 0, rightDir = 0;

  // Apply PID control to maintain target velocities
  if (currentTime - lastPIDUpdateTime >= PID_UPDATE_INTERVAL) {
    // Calculate time delta in seconds
    float deltaT = (currentTime - lastPIDUpdateTime) / 1000.0;
    
    // Compute PID outputs for left motor
    leftPID.evalu(leftVelocity, leftTargetVelocity, deltaT, leftPower, leftDir);
    
    // Compute PID outputs for right motor
    rightPID.evalu(rightVelocity, rightTargetVelocity, deltaT, rightPower, rightDir);
    
    // Apply the computed control signals to motors with direction adjustment
    setMotorSpeed(motor1, leftPower, leftDir * LEFT_MOTOR_DIRECTION);
    setMotorSpeed(motor2, rightPower, rightDir * RIGHT_MOTOR_DIRECTION);

    // Store the current direction for velocity calculation
    lastLeftDir = leftDir;
    lastRightDir = rightDir;

    lastPIDUpdateTime = currentTime;
  }


  // Publish sensor data to ROS2 at the specified interval
  if (currentTime - lastPublishTime >= PUBLISH_INTERVAL) {
    publishOdometryData();
    publishBatteryData();
    publishIMUData();
    publishGPSData();
    publishStatusData();
    
    lastPublishTime = currentTime;
  }
}

// Function to receive ROS2 messages (format: <CMD,param1,param2,...>)
void receiveROS2Message() {
  if (Serial.available() > 0) {
    char rc = Serial.read();
    
    // Start of message
    if (rc == MSG_START_MARKER) {
      receivingData = true;
      dataIndex = 0;
      memset(receivedChars, 0, numChars);
    }
    // End of message
    else if (rc == MSG_END_MARKER) {
      receivingData = false;
      newData = true;
    }
    // Message content
    else if (receivingData) {
      if (dataIndex < numChars - 1) {
        receivedChars[dataIndex] = rc;
        dataIndex++;
      }
    }
  }
}

// Function to parse and execute received commands
void parseAndExecuteCommand() {
  // First character is the command type
  char cmdType = receivedChars[0];
  
  // Parse parameters (splitting by commas)
  int paramIndex = 0;
  char* params[10]; // Can handle up to 10 parameters
  
  // Skip the command type
  char* token = strtok(receivedChars + 1, ",");
  
  // Parse parameters
  while (token != NULL && paramIndex < 10) {
    params[paramIndex++] = token;
    token = strtok(NULL, ",");
  }
  
  // Execute command based on type
  switch (cmdType) {
    case CMD_MOVE:
      if (paramIndex >= 2) {
        int speedLeft = atoi(params[0]);
        int speedRight = atoi(params[1]);
        // Constrain speeds between -MOTOR_SPEED and MOTOR_SPEED
        speedLeft = constrain(speedLeft, -MOTOR_SPEED, MOTOR_SPEED);
        speedRight = constrain(speedRight, -MOTOR_SPEED, MOTOR_SPEED);
        
        // Convert speed commands to target velocities
        leftTargetVelocity = convertSpeedToVelocity(speedLeft);
        rightTargetVelocity = convertSpeedToVelocity(speedRight);
        
        // If the target velocity is zero, reset the PID to prevent integral windup
        if (leftTargetVelocity == 0) leftPID.reset();
        if (rightTargetVelocity == 0) rightPID.reset();
      }
      break;
      
    case CMD_LIGHTS:
      if (paramIndex >= 2) {
        int headlight = atoi(params[0]);
        int brakelight = atoi(params[1]);
        // Set lights
        if (headlight == 1) turnOnHeadlight();
        else turnOffHeadlight();
        
        if (brakelight == 1) turnOnBrakelight();
        else turnOffBrakelight();
      }
      break;
      
    case CMD_RESET_ENC:
      leftEncoderCount = 0;
      rightEncoderCount = 0;
      leftDistanceMM = 0;
      rightDistanceMM = 0;
      prevLeftCount = 0;
      prevRightCount = 0;
      // Reset PID controllers
      leftPID.reset();
      rightPID.reset();
      break;

    case CMD_HEARTBEAT:
      Serial.println("<K,1>");
      break;
  }
}

// Function to publish odometry data
void publishOdometryData() {
  char buffer[64];
  snprintf(buffer, sizeof(buffer), "<%c,%ld,%ld,%.2f,%.2f>", 
           MSG_ODOM, 
           leftEncoderCount, 
           rightEncoderCount, 
           leftDistanceMM, 
           rightDistanceMM);
  Serial.println(buffer);
}

// Function to publish battery data
void publishBatteryData() {
  char buffer[32];
  snprintf(buffer, sizeof(buffer), "<%c,%d,%d>", 
           MSG_BATTERY, 
           batteryVoltage, 
           batteryPercentage);
  Serial.println(buffer);
}

// Function to publish IMU data
void publishIMUData() {
  char buffer[96];
  snprintf(buffer, sizeof(buffer), "<%c,%.2f,%.2f,%.2f,%.2f,%.2f,%.2f,%.2f,%.2f,%.2f,%.2f>", 
           MSG_IMU, 
           aX, aY, aZ, 
           gX, gY, gZ, 
           mX, mY, mZ, 
           mDirection);
  Serial.println(buffer);
}

// Function to publish GPS data
void publishGPSData() {
  char buffer[64];
  int valid = gps.location.isValid() ? 1 : 0;
  snprintf(buffer, sizeof(buffer), "<%c,%.6f,%.6f,%d,%d>", 
           MSG_GPS, 
           gps.location.isValid() ? gps.location.lat() : 0.0, 
           gps.location.isValid() ? gps.location.lng() : 0.0, 
           gps.satellites.isValid() ? gps.satellites.value() : 0,
           valid);
  Serial.println(buffer);
}

// Function to publish status data
void publishStatusData() {
  char buffer[32];
  snprintf(buffer, sizeof(buffer), "<%c,%d,%d,%d,%d,%d,%d>", 
           MSG_STATUS, 
           toggleSwitch1_state, 
           toggleSwitch2_state,
           !digitalRead(LEFT_WHEEL_SW_PIN),
           !digitalRead(RIGHT_WHEEL_SW_PIN),
           FWD_RELAY_ON ? 1 : 0,
           AFT_RELAY_ON ? 1 : 0);
  Serial.println(buffer);
}

// Function to update IMU sensor data
void updateIMSData() {
  // Update accelerometer
  if (mySensor.accelUpdate() == 0) {
    aX = mySensor.accelX();
    aY = mySensor.accelY();
    aZ = mySensor.accelZ();
    aSqrt = mySensor.accelSqrt();
  }
  
  // Update gyroscope
  if (mySensor.gyroUpdate() == 0) {
    gX = mySensor.gyroX();
    gY = mySensor.gyroY();
    gZ = mySensor.gyroZ();
  }
  
  // Update magnetometer
  if (mySensor.magUpdate() != 0) {
    mySensor.beginMag();
    mySensor.magUpdate();
  }
  
  // Read magnetometer values
  if (mySensor.magUpdate() == 0) {
    mX = mySensor.magX();
    mY = mySensor.magY();
    mZ = mySensor.magZ();
    mDirection = mySensor.magHorizDirection();
  }
}

// Function to calculate distance from encoder counts
float calculateDistance(unsigned long counts) {
  float revolutions = counts / TRANSITIONS_PER_REV;
  return revolutions * PI * WHEEL_DIAMETER_MM;
}

// Function to check the battery level
void readBatteryLevel() {
  batteryVoltage = analogReadMilliVolts(BATTERY_MONITOR_PIN);
  batteryPercentage = map(batteryVoltage, 2570, 3050, 0, 100);
  if(batteryPercentage > 100) batteryPercentage = 100;
  if(batteryPercentage < 0) batteryPercentage = 0; 
}

// Function to read toggle switches
void readToggleSwitches() {
  toggleSwitch1_state = digitalRead(TOGGLE_SW1_PIN);
  toggleSwitch2_state = digitalRead(TOGGLE_SW2_PIN);
}

// Function to turn on headlight relay
void turnOnHeadlight() {
  digitalWrite(FWD_RELAY_CTRL_PIN, HIGH);
  FWD_RELAY_ON = true;
}

// Function to turn off headlight relay
void turnOffHeadlight() {
  digitalWrite(FWD_RELAY_CTRL_PIN, LOW);
  FWD_RELAY_ON = false;
}

// Function to toggle headlight relay
void toggleHeadlight() {
  if(FWD_RELAY_ON) {
    digitalWrite(FWD_RELAY_CTRL_PIN, LOW);
    FWD_RELAY_ON = false;
  } else {
    digitalWrite(FWD_RELAY_CTRL_PIN, HIGH);
    FWD_RELAY_ON = true;
  }
}

// Function to turn on brakelight relay
void turnOnBrakelight() {
  digitalWrite(AFT_RELAY_CTRL_PIN, HIGH);
  AFT_RELAY_ON = true;
}

// Function to turn off brakelight relay
void turnOffBrakelight() {
  digitalWrite(AFT_RELAY_CTRL_PIN, LOW);
  AFT_RELAY_ON = false;
}

// Function to toggle brakelight relay
void toggleBrakelight() {
  if(AFT_RELAY_ON) {
    digitalWrite(AFT_RELAY_CTRL_PIN, LOW);
    AFT_RELAY_ON = false;
  } else {
    digitalWrite(AFT_RELAY_CTRL_PIN, HIGH);
    AFT_RELAY_ON = true;
  }
}

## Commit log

2025-03-11 Designed power distribution PCB
    [Dark_Passenger_Power Distro.kicad_pcb, Dark_Passenger_Power Distro.kicad_sch]
2025-03-20 PCB Design Updates
    [Dark_Passenger_Power Distro.kicad_pcb, Dark_Passenger_Power Distro.kicad_sch]
2025-03-20 Wiring updates for GPIOs
2025-03-20 New PCB Designed
    [Dark_Passenger_Arduino Shield.kicad_pcb, Dark_Passenger_Arduino Shield.kicad_sch]
2025-03-24 Updates to wiring interconnect
2025-03-25 Interconnect Updates testing ESP32
2025-03-25 ESP32 MCU Validated Code
    This is code that I've confirmed working with a ESP32-S3-WROOM-1 board. Once all relevant code is validated, I can create a PCB to allow for all components to interface. This PCB will allow all these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
2025-03-27 Reorganized power distro PCB directory
2025-03-27 Designed Base MCU PCB Rev1.0
    [Dark_Passenger_Arduino Shield.kicad_pcb, Dark_Passenger_Arduino Shield.kicad_sch, Dark_Passenger_Base_MCU.kicad_pcb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]
2025-03-29 Electrical Interconnect updates from turret PCB
2025-03-29 Updates to Base PCB
    [Dark_Passenger_Base_MCU-B_Cu.gbr, Dark_Passenger_Base_MCU-B_Mask.gbr, Dark_Passenger_Base_MCU-B_Paste.gbr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]
2025-03-29 Designed turret PCB
    [Dark_Passenger_Turret_MCU-B_Cu.gbr, Dark_Passenger_Turret_MCU-B_Mask.gbr, Dark_Passenger_Turret_MCU-B_Paste.gbr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]
2025-03-29 Updated CAD renders of board
2025-03-29 Updated readme with photos and PCB details.
2025-03-29 Reorganized and renamed PCB render files
    [Dark_Passenger_Base_MCU-B_Cu.gbr, Dark_Passenger_Base_MCU-B_Mask.gbr, Dark_Passenger_Base_MCU-B_Paste.gbr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]
2025-03-29 CAD View updated with render
2025-04-05 Updates to electrical interconnect based on board assembly.
2025-04-05 PCB Updates based on board assembly.
2025-04-05 Updates to code based on new pinouts from PCBs
    [Dark_Passenger_Base_MCU.kicad_pcb, Dark_Passenger_Base_MCU.kicad_sch, Dark_Passenger_Turret_MCU.kicad_pcb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]
2025-04-13 Updated Arduino Code
    Compiled functionality from testing scripts into the first main serial controlled script.
2025-04-14 Ported encoder readout to the command handler.
2025-04-15 Added ROS2 template package
    [robot.urdf.xacro]
2025-04-15 Reorganized into a dedciated ROS2 workspace for easier configuration on multiple platforms
    [robot.urdf.xacro]
2025-04-15 Created urdf model collision and inertia macros
    [inertial_macros.xacro, robot.urdf.xacro, robot_core.xacro]
2025-04-15 fixed mislabelled xacro
    [robot_core.xacro]
2025-04-15 Implemented GazeboSim
    [robot_core.xacro]
2025-04-16 Modified control plugins to interface with Gazebo Harmonic
    [gazebo_control.xacro, obstacles.world.sdf, robot.urdf.xacro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]
2025-04-16 Updated world file to handle sensor plugins.
    [obstacles.world.sdf]
2025-04-16 Added Lidar Feature to Gazebo and Rviz
    [lidar.xacro, robot.urdf.xacro]
2025-04-17 Added ROS launch script for LIDAR.
2025-04-17 Removed collision physics for Lidar since internal to box.
    [lidar.xacro]
2025-04-17 Added standard Camera capability.
    [camera.xacro, robot.urdf.xacro]
2025-04-17 Integrated rgb depth camera
    [depth_camera.xacro, robot.urdf.xacro]
2025-04-22 Added quick disconnect connector
2025-04-24 Created ESP32 MCU hardware bridge ROS2 package
2025-04-24 Created base bridge for interfacing with base esp32 over serial
2025-04-24 Added topic router but experiencing random crashes due to indexing out of bounds.
    [base_rx_topic_router.py]
2025-05-07 Created PID tuner to help tune controllers using serial plotter
2025-05-07 Added PID controller for smoother motor commands
2025-05-08 Created controller to convert Twist cmd_vel to motor speeds.
2025-05-09 Added ros2_control plugin support
    [my_controllers.yaml, robot.urdf.xacro, ros2_control.xacro]
2025-05-09 Passing launch parameters to rsp.launch
    [robot.urdf.xacro, robot_core.xacro]
2025-05-21 Initial steps to integrate ros2_control with hardware
    [ros2_control.xacro]

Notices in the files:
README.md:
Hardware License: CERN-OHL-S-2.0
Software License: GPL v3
